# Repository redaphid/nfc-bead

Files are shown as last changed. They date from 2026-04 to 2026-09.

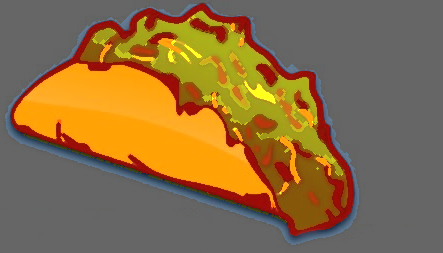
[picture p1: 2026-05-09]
beads/filibertos-taco/extract_debug.png

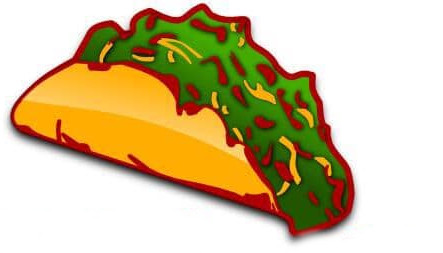
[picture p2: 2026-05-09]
beads/filibertos-taco/just-taco.jpg

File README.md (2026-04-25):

# nfc-bead

Reusable scaffolding for designing two-half snap-fit NFC charms / beads from a 2D silhouette SVG. Built around a Blender + Python pipeline that handles the boring mechanical bits (split, pegs, NFC pocket, string hole) so creative sessions can focus on the silhouette and aesthetic.

First charm built with this recipe: the [Wooli mammoth](https://github.com/redaphid/wooli-bead) (private). This repo is the template extracted from that work.

## What's in here

| Path | Purpose |
|---|---|
| `prompts/nfc-bead/prompt.md` | The technical recipe — dimensions, pipeline order, gotchas. Drop this into any new Claude session as the scaffolding for a new charm. |
| `.claude/skills/nfc-bead/SKILL.md` | Claude Code skill that auto-triggers on new-charm requests, loads the prompt, and drives the workflow. |
| `.claude/skills/nfc-bead/blender_mcp_addon.py` | Bundled Blender MCP addon (from [ahujasid/blender-mcp](https://github.com/ahujasid/blender-mcp)) so the live MCP workflow doesn't need an internet round-trip. |
| `.claude/settings.json` | Project Claude settings — pre-allows Blender / uvx / python invocations. |
| `.mcp.json` | Project-level MCP server config. Wires up the Blender MCP server (`uvx blender-mcp`). |
| `build_charm.py.example` | Reference implementation of the full Blender pipeline. Copy to `build_<charm>.py` and edit the CONFIG block at the top per charm. |
| `CLAUDE.md` | Working norms for Claude Code in this repo (branch model, multi-color defaults, live-MCP preference). |
| `SETUP.md` | One-time and per-session setup for the live Blender MCP workflow. **Read this if you want to drive Blender live**, otherwise headless works without it. |
| `tools/launch.ps1` | One-shot Windows launcher: opens Blender with the addon installed, enabled, and the MCP server running. See *MCP — Blender* below. |
| `tools/blender_bootstrap.py` | What `launch.ps1` actually feeds to Blender via `--python`. Idempotent. |
| `beads/<name>/` | Per-charm work tree: silhouette SVG, `build_<name>.py`, `print/` STLs + `.blend`, `stages/NN_*.blend` snapshots + `.md` notes, `DEBUGGING_LOG.md`. The rezz branch ships `beads/rezz/`. |
| `GUIDE.md` | Long-form walkthrough with lessons learned from the original Wooli build. |

## Quick start

1. **Branch off `main` for the new bead.** Per-charm work always lives on its own branch named after the bead — never on `main`:
   ```bash
   git checkout main && git pull --ff-only
   git checkout -b <bead-name>          # e.g. rezz, mammoth, octopus
   ```
2. Open this repo in Claude Code. The `nfc-bead` skill auto-loads.
3. Say something like: *"new charm — here's the silhouette"* and attach an SVG. The skill reads the prompt, asks the right questions, and walks the build. **Just talk to Claude — it knows about the branch convention, the launcher, and will run you through Blender setup if you don't have it going yet.**
4. Or, manually: read `prompts/nfc-bead/prompt.md` yourself, copy `build_charm.py.example` to `beads/<name>/build_<name>.py`, edit the CONFIG block, run headless:
   ```
   blender --background --python beads/<name>/build_<name>.py
   ```

## MCP — Blender (live workflow)

`.mcp.json` configures the [Blender MCP](https://github.com/ahujasid/blender-mcp) server (`uvx blender-mcp`) so Claude Code can drive Blender live — you watch geometry build in the viewport and can steer mid-build.

**One-shot launcher** — `tools/launch.ps1` opens Blender with the addon installed, enabled, and the MCP server running, all in one command:

```powershell
.\tools\launch.ps1                       # rezz bead (default)
.\tools\launch.ps1 -Bead wooli           # different bead's last-saved .blend
.\tools\launch.ps1 -BlendFile foo.blend  # arbitrary file
```

The launcher runs `tools/blender_bootstrap.py` inside Blender; it's idempotent (copies-if-stale + enables + saves prefs + starts server), so re-running it after a crash always brings you back to a working state. After Blender opens, run `/mcp` in Claude Code to (re)connect.

If you'd rather click through it manually, **[`SETUP.md`](./SETUP.md)** has the full step-by-step plus troubleshooting. Either way the bundled addon at `.claude/skills/nfc-bead/blender_mcp_addon.py` is what gets installed — no GitHub round-trip.

Headless `blender --background --python` works without any of this — the MCP is only for live interactive sessions.

## Default charm spec

| Feature | Value |
|---|---|
| Width | 25 mm (sized for Kandi bracelets) |
| Thickness | 5 mm (2.5 mm × 2 halves) |
| String hole | 2 mm dia, X-axis through head |
| NFC pocket | 10.5 mm dia × 0.8 mm deep (NTAG215, 10mm sticker) |
| Pegs | 3 × 2 mm dia × 1.5 mm tall, 0.1 mm clearance per side |

Override any of these per charm in the CONFIG block.

## Print settings

PLA or PETG, 0.12–0.16 mm layers, 100% infill, no supports. Bottom half flipped 180° around X (pegs face up, silhouette on build plate). Top half prints with peg-hole face on the build plate.

## License

Private template repo. Do whatever you want with it.

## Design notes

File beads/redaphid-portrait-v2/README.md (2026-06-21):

# Redaphid Portrait — v2 (new design)

The `redaphid-portrait` charm rebuilt on the "new design" learned from
`gymnast-medallion` (recipe gotchas #29–32), **keeping the portrait outline as
the bead shape** (NOT a round medallion). Same multi-color portrait — cream
face, magenta hair, glowing eyes — just slimmer with a one-sided string hole and
self-starting pegs.

## What changed vs the original `redaphid-portrait`

| Aspect | Original | v2 |
|---|---|---|
| Thickness | 4.0 mm symmetric (2.0 + 2.0) | **3.5 mm asymmetric**: Bottom 2.0 + Top 1.5 (slimmer decorated front) |
| String hole | 2.0 mm, on the split plane (half-groove each side) | **1.2 mm, entirely in the thick Bottom half** (gotcha #23/#31), ~0.4 mm walls |
| Pegs | 2.0 mm, 0.1 mm clearance, blunt | 2.0 mm, **0.05 mm clearance + 0.3 mm chamfered tips** (gotcha #29/#30) so they self-start instead of needing force |

Everything else is the original portrait pipeline: silhouette extrude → hole →
asymmetric split → NFC pocket → peg sockets (in Bottom) → pegs (on Top) → Hair
decoration (magenta) + Eyes (Decoration, glow). Pegs stay on Top per the
charm's chosen layout, so the Top prints **show-face-down** (hair/eyes on the
plate, pegs up); the build exports STLs already in that orientation.

## Source

- `silhouette.svg` + `hair.svg` copied from `beads/redaphid-portrait` (tuned).
- `extract_silhouette.py` (reference) re-extracts both from the source
  screenshot `C:\Users\hypnodroid\Pictures\Screenshots\Screenshot 2026-04-25 235837.png`.

## Files

| File | What |
|---|---|
| `silhouette.svg` / `hair.svg` | portrait outline (+eyes) and haircut shape |
| `build_redaphid.py` | headless Blender build → 4 STLs + blend (+ direct print-oriented export) |
| `print/Bottom.stl` | cream — thick back half: NFC pocket, peg sockets, string hole |
| `print/Top.stl` | cream — thin front half + pegs (prints show-face-down) |
| `print/Hair.stl` | magenta — raised haircut |
| `print/Decoration.stl` | glow — the two eyes |
| `print/redaphid-portrait-v2.3mf` | slicer bundle (Bottom + Top+Hair+Decoration merged) |
| `preview.png` | render (viewed from the show-face side) |

## Rebuild

```sh
"D:\tools\blender\blender.exe" --background --python beads/redaphid-portrait-v2/build_redaphid.py
uv run nfc-make-3mf --dir beads/redaphid-portrait-v2/print --out beads/redaphid-portrait-v2/print/redaphid-portrait-v2.3mf
```

## Verified

All four parts watertight (Decoration = 2 eyes = 2 bodies, expected). String
hole open in the Bottom (ray cast: solid/void/void/solid, 0.4 mm walls). Pegs
single-body welded to Top with chamfered tips. Three peg positions pass the
silhouette + NFC + hole clearance checks.

## Watch on print

- 0.4 mm walls around the 1.2 mm string hole bridge fine on a tuned printer; bump `BOTTOM_THICK` toward 2.2 mm if they sag.
- Top prints show-face-down — the multi-color hair/eyes are the first layers (mind the bed finish). The original tracked this as `top-v5b-1stlayer`.

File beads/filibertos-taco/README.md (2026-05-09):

# Filiberto's Taco

A two-half NFC charm shaped like a cartoon taco — yellow shell, green lettuce, red outline — built as a multi-color print on the Centauri Carbon 2.

## Source

- `just-taco.jpg` — the reference cartoon taco art (yellow shell + green lettuce + red outline on white background).
- `silhouette.svg` — outer body silhouette extracted from the JPEG via custom multi-color extraction (Pillow + numpy + scipy + skimage). Single Fourier-smoothed closed path, 400 verts.
- `region_yellow.svg`, `region_green.svg`, `region_red.svg` — color-segmented decoration regions in the same coordinate frame as `silhouette.svg`.
- `extract_debug.png` — segmentation overlay (blue=outer, red=outline, yellow=shell, green=lettuce). Sanity-check before importing.

The original `taco.svg` Potrace tracing was discarded — it was a B&W line-art trace, not a filled silhouette, and produced a hollow body with even-odd fill. The JPEG-based extraction yields a clean filled outer outline plus three color regions.

## Why this charm exists

Exercises the multi-color decoration pattern: rather than a single `Decoration` object, the show face hosts three overlapping color regions (yellow shell base, green lettuce on top, red outline detail) extruded as raised relief. Slicer assigns one filament per region.

It also stress-tests the SVG → silhouette pipeline against a *bitmap* input — Potrace traces of pen-and-ink illustrations don't make clean filled silhouettes; you need a color-aware mask of the colored regions. That extraction lives at the top of `build_filibertos_taco.py` documentation, not as a generalized skill (yet).

## Key creative decisions

| Decision | Cost |
|---|---|
| Multi-color decoration as 3 separate STLs (Yellow / Green / Red) | More slicer setup; user assigns filaments per object. Simpler than paint-on-color in Bambu Studio / Elegoo Slicer. |
| Show face raised relief (0.4 mm) instead of recessed groove | Bumpy show face but reliable bridge-free print; recess would need the slicer to color-paint the same Top STL. |
| String hole tube entirely inside Top half (`HOLE_Z_OFFSET=1.25`) | First-layer adhesion is solid silhouette across the seam; tube becomes a small interior cavity bridged twice (~0.5 mm wall above and below). Recipe gotcha #23. |
| Bottom in print orientation already at end of build (centered-mesh pipeline) | Sets `nfc_export_flip_override` so `bead-stl-export` doesn't apply its default 180° flip. Recipe gotcha #16. |
| 3 pegs (not 4) at `(7.5,-6.0)`, `(-9.5,0.0)`, `(7.5,2.5)` | Triangulated; auto-fit found ≥1mm clearance from NFC and silhouette boundary, ≥1mm from string-hole tube. |
| Concatenate the 3 color STLs into a unified `Decoration.stl` for the 3MF builder | Lets `nfc-make-3mf` ship a slicer-ready bundle. Per-color STLs remain separate in `print/` for users with multi-filament setups who want explicit per-region color control. |

## What's transferable / what's specific

**Transferable** (could become recipe defaults):
- `nfc_export_flip_override` discipline for centered-mesh build pipelines — already in recipe gotcha #16.
- Multi-color decoration as raised relief at `top_z + ε` rather than recessed cuts.
- Cropping decorations to silhouette via boolean INTERSECT with a duplicate-extruded Top.

**Specific** (tuned to this taco):
- Custom extraction script at the top of `build_filibertos_taco.py`'s sibling files. It assumes a white-background cartoon with red/yellow/green color clusters. Other illustrations will need per-charm tuning of the channel-discriminator thresholds.
- 25 mm × 17 mm bounding box with NFC at `(0, 0.5)` and `HOLE_Y=5.0` — auto-fit picked these for this silhouette's specific shape.

## Files

| File | What it is |
|---|---|
| `just-taco.jpg` | source reference image |
| `silhouette.svg` | outer body silhouette (used by `build_filibertos_taco.py`) |
| `region_yellow.svg` / `region_green.svg` / `region_red.svg` | color region inputs |
| `extract_debug.png` | extraction sanity overlay |
| `build_filibertos_taco.py` | Blender pipeline — extrude → split → NFC + hole + pegs → 3 decoration extrudes |
| `print/Bottom.stl` | back half — silhouette face on bed, pegs up |
| `print/Top.stl` | front half — peg sockets in inner face, show face up |
| `print/DecorationYellow.stl` / `DecorationGreen.stl` / `DecorationRed.stl` | per-color decoration regions, 0.4 mm raised relief on Top |
| `print/Decoration.stl` | concatenation of the 3 color STLs (used by `nfc-make-3mf`) |
| `print/filibertos-taco.3mf` | Bambu Studio / Elegoo Slicer bundle (Bottom + Top with Decoration assembly) |
| `print/filibertos-taco_charm.blend` | live Blender scene at end of build — re-launch via `tools/launch.ps1 -Bead filibertos-taco` |
| `stages/01_built_verified.blend` | snapshot at the post-build verification step |
| `PRINT_LOG.md` | per-print iteration log (failure modes + parameter changes) |

## Two style variants

Build script `build_filibertos_taco.py` switches between two looks by
reading `STYLE` (env var `FILIBERTOS_TACO_STYLE`, scene custom prop
`nfc_taco_style`, default `"painted"`):

| Style | Decoration source | Output |
|---|---|---|
| `painted` (default) | `region_*.svg` (filled color regions, k-means extraction) | `print/` — 4-filament cartoon look |
| `neon` | `stroke_*.svg` (line strokes, dilate-XOR extraction) | `print/neon/` — 2-3-filament neon-sign look on a black body |

Switch in Blender:
```python
bpy.context.scene["nfc_taco_style"] = "neon"
exec(open(r"...build_filibertos_taco.py").read(), {"__name__":"__main__"})
```

Re-extract decoration sources independently:
```sh
uv run python beads/filibertos-taco/extract_regions.py   # k-means → region_*.svg
uv run python beads/filibertos-taco/extract_strokes.py   # dilate-XOR → stroke_*.svg
```

## Re-build / re-export

```sh
# from a fresh shell, in the repo root:
.\tools\launch.ps1 -Bead filibertos-taco
# in Claude Code:
/mcp                       # reconnect bridge
# Then in conversation:
exec(open(r"D:\Projects\nfc-bead\beads\filibertos-taco\build_filibertos_taco.py").read(), {"__name__": "__main__"})
```

The build sets `nfc_export_flip_override` automatically. After it completes:

```sh
# back in the host shell:
uv run python -c "import trimesh; from pathlib import Path; LAT=Path('tmp/latest'); parts=[trimesh.load(LAT/n) for n in ('DecorationYellow.stl','DecorationGreen.stl','DecorationRed.stl')]; trimesh.util.concatenate(parts).export(LAT/'Decoration.stl')"
uv run nfc-printability-check
uv run nfc-make-3mf
```

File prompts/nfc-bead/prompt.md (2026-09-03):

# NFC Bead / Charm — Technical Recipe

Use this as the technical scaffolding for any new two-half NFC charm. Drop it in at the start of a session, then describe the *creative* side — silhouette, theme, vibe, dimensions if non-default — and let the rest follow this recipe.

A working reference implementation lives at `build_charm.py` in this repo (built for the Wooli mammoth). Treat it as the canonical pipeline; copy and adapt the CONFIG block for new charms.

---

## What we're building

A **two-half snap-fit charm** for Kandi-style bracelets:

- A 2D silhouette (from SVG) extruded to a flat-ish 3D shape
- **Cut horizontally through the middle** into a top half and a bottom half
- **NFC sticker pocket** recessed into the inside face of the bottom half (so the sticker sits flush)
- **Friction-fit pegs** on the bottom half + matching holes on the top half (no glue — press fit)
- **String hole** through the head/top so it can hang off a bracelet or cord

Target NFC tag: NTAG215, 10mm diameter sticker (e.g. `https://www.amazon.com/dp/B0CH3XS569`). Pocket sizing assumes that.

---

## Default dimensions (override per-charm as needed)

| Feature | Value | Notes |
|---|---|---|
| Overall width | 25 mm | sized for Kandi bracelets; scale on import |
| Total thickness | 5 mm | split as 2.5 mm + 2.5 mm |
| String hole | 2 mm dia | runs along the X axis (lengthwise through the head/top) |
| NFC pocket | 10.5 mm dia × 0.8 mm deep | on the inside face of the bottom half only |
| Peg diameter | 2 mm | bumped up from 1.5 — stronger, less prone to snapping |
| Peg height | 1.5 mm | |
| Peg hole clearance | 0.1 mm per side | so hole radius = (peg_dia + 0.2) / 2 |
| Number of pegs | 3 | triangulated for stable alignment |

**Peg placement rules** (pick 3 spots that satisfy all of these):
- Inside the silhouette (raycast-verify before committing)
- ≥ ~1 mm clear of the NFC pocket edge
- ≥ ~1 mm clear of the string hole
- Triangulated, not collinear (gives torsional stability)
- ≥ ~1 mm from the silhouette edge (so the wall around the peg hole isn't paper-thin)

**String-hole placement rules** — the hole hangs the bead off a bracelet, so the
wall around it is a load-bearing feature. Don't pick the obvious spot if it
leaves thin material:

- Y must sit on a *wide* part of the silhouette — not on a narrow tip, ear-
  flap, hair-ridge, or other protrusion. Aim for the band where the
  silhouette is at full width.
- ≥ 2.5 mm of solid silhouette **above** the hole (between hole top and the
  silhouette's top edge). With a 2 mm-dia hole that's ≥ 1.5 mm of wall above.
  Less than that, the bead snaps off the bracelet under load.
- ≥ 1.5 mm of solid silhouette to either side at the hole's Y. The hole runs
  along X, so the silhouette's X-extent at the chosen Y must comfortably
  exceed the bead's diameter at the hole.
- For shapes whose top is a narrow protrusion (mammoth tusk, shaggy hair
  bumps, animal ears), drop the hole *down* into the wider head/forehead
  body even if it costs aesthetic intent. The dangling bead doesn't notice
  where the cord exits, but the wall above does.

---

## Pipeline (in order — order matters)

```
SVG silhouette
  → Import into Blender as 2D curve, join, set fill_mode='BOTH', resolution_u=64
  → Convert to mesh, scale to TARGET_WIDTH (mm)
  → Fill any interior gaps that would conflict with features (NFC pocket, pegs)
  → Extrude flat profile to THICKNESS  (use Extrude, NOT Solidify)
  → Boolean DIFFERENCE for the string hole (full bead, before split)
  → Box-cut INTERSECT to split into top + bottom halves at z_mid
  → Boolean DIFFERENCE for NFC pocket on the bottom half
  → Boolean DIFFERENCE for peg holes on the top half  (POST-SPLIT — see gotcha)
  → Boolean UNION to add pegs onto the bottom half     (NOT mesh join)
  → Flip bottom 180° around X for printing; export both STLs
```

---

## Critical gotchas (these will bite you if ignored)

### 1. Cut peg holes AFTER splitting, never before
If you cut peg holes into the full bead first and then box-cut to split, the split plane is **coplanar** with the peg-hole bottom. The EXACT solver collapses the holes — they get sealed shut and disappear silently. Always split first, then cut peg holes into the top half with cutters that extend **1 mm below the inner face** so the cutter is unambiguously through-going:

```python
cutter_bottom = inner_face_z - 1.0          # extend past the inner face
cutter_top    = inner_face_z + PEG_HEIGHT + 0.3
```

### 2. Always use the EXACT boolean solver
`solver = 'EXACT'`. The FAST solver routinely produces non-manifold output on shapes like this. Set this on every modifier.

### 3. Add pegs with boolean UNION, not mesh join
`bpy.ops.object.join()` leaves overlapping coplanar faces where the peg cylinder meets the inner face → 1000+ non-manifold edges. Use a UNION boolean modifier instead. It welds the peg to the half cleanly.

### 4. Use Extrude, not Solidify, when the silhouette has interior holes
Solidify produces broken topology around interior boundaries (e.g., the gap between mammoth legs, the inside of an "O"). Plain extrude is clean.

### 5. Tight `remove_doubles` threshold
Use `0.005` mm. `0.02+` will collapse small features and ruin the geometry. Run `remove_doubles` + `normals_make_consistent(inside=False)` after every boolean.

### 6. Filling interior gaps cleanly
If the silhouette has an interior hole that overlaps a feature (e.g., an NFC pocket lands on the trunk-gap hole), don't try to patch it in the SVG with an overlapping rectangle — that creates a separate boundary that won't merge. Instead, in mesh edit mode, select the boundary edges of the unwanted hole by coordinate range and call `bpy.ops.mesh.fill()`. Other interior holes you want to keep (like the leg gap) are untouched.

### 7. Don't voxel-remesh
Voxel remesh seals small holes (string hole, peg holes) at any reasonable resolution. Skip it.

### 8. Verify everything with raycasts before exporting
After the build, raycast through where each hole should be:
```python
result = eval_obj.ray_cast(origin, direction)
# result[0] is True if it hit something — i.e. the hole is BLOCKED
```
Verify: string hole open through the head, each peg hole open through the top, each peg position lands on solid geometry inside the silhouette.

Note: peg holes are *blind* recesses (cutter depth = `PEG_HEIGHT + 0.3 mm`), not through-going. The raycast through a peg hole will *intentionally* report `BLOCKED at z=PEG_HEIGHT+0.3`. That's the right answer — they're sockets the pegs bottom into.

### 9. Build raised face decorations as flat ribbon meshes, not curve-bevel-then-clip
For any raised graphic on the show face (rezz spiral, embossed text, ridged pattern), the obvious workflow — build a curve, set `bevel_depth = arm_width / 2` for a tube cross-section, convert to mesh, then INTERSECT with a slab to flatten — **silently produces an empty mesh**. The EXACT solver doesn't reliably handle a tube tangent to a thin slab; it collapses the entire mesh. No error is raised; you'll see `dims: (0.0, 0.0, 0.0)` in the output and a missing object in the viewport.

Build the ribbon directly instead. Sample the centerline path, compute inner/outer offsets perpendicular to the tangent, build quads with `mesh.from_pydata`, extrude vertically. Reliable, manifold, fast.

Do **not** add an explicit "end-cap" face to close the open ends of an open ribbon. A face like `[inner_start, outer_start, outer_end, inner_end]` will draw one gigantic quad spanning from start of the ribbon to end, visible as a straight line cutting across the disc. Extrusion auto-creates side-wall faces along the boundary edges, which closes the ends as small rectangular walls — no explicit cap needed.

### 10. Don't `origin_set BOUNDS` on objects whose mesh-local origin is meaningful
If an object's mesh was built around a meaningful origin point (the centerline of a spiral, the centroid of a silhouette), running `bpy.ops.object.origin_set(type='ORIGIN_GEOMETRY', center='BOUNDS')` before placing it will move the *bbox center* to that origin — but for an asymmetric mesh (e.g. a spiral with a notch trimmed out, an outline with a tail), the bbox center isn't where the meaningful origin was. The object lands subtly off-center.

`origin_set BOUNDS` is for objects whose origin doesn't matter (`Bottom`, `Top` halves — they were extruded from a centered silhouette and bbox center matches geometric center). Skip it for decorations whose mesh-local `(0,0,0)` is geometrically significant; place them via `obj.location` directly.

### 11. Lift overlapping decorations by ε to avoid Z-fighting
When a separately-printed decoration (raised spiral, embossed text) sits on the host face, both at the same Z, viewport rendering will Z-fight at the boundary. Lift the decoration by 0.01 mm (`spiral.location.z = host_top_z + 0.01`). Slicer tolerances absorb this — they print fused — and the viewport is artifact-free.

### 12. Don't cut decorative "clearance" against features the decoration never touches
A common reflex is to trim the show-face decoration around features like the string hole "for clearance." If the feature physically interacts with the decoration, yes — trim. But the string hole runs *horizontally through the bead body*; the decoration sits on the *outer face*; they never touch. Cutting a notch in the decoration to "clear" the hole's top opening just leaves a visible bite in the decoration that adds nothing functional. Question whether the cut is necessary before adding it.

### 13. Drill the string hole at the mesh's *actual* z-midpoint, never at `THICKNESS/2`
If your build pipeline centers the FullBead on the origin (so verts span `−THICKNESS/2..+THICKNESS/2`), hard-coding `location=(0, HOLE_Y, THICKNESS/2)` puts the hole at the **top face** of the bead — entirely inside the Top half after the box-cut split. Bottom ends up with no opening, and you can't thread a cord through. Compute `z_mid` from the live mesh:

```python
zs = [v.co.z for v in mesh.data.vertices]
z_mid = (min(zs) + max(zs)) / 2.0
location = (0, HOLE_Y, z_mid)
```

This is silent — the build runs to completion, the STL passes manifold checks, and you only notice when you try to thread a cord (or run a side-view raycast). The reference `build_charm.py.example` doesn't trip this because it leaves the silhouette at z=0..THICKNESS rather than centering it; centered-mesh builds need the live z_mid.

### 14. Pegs go on Bottom — multi-color decoration on Top precludes flipping it
The recipe's "pegs on Bottom + sockets on Top" assignment isn't arbitrary. With pegs on Top hanging *down* off the inner face, the slicer flags the Top assembly as a cantilever (the body is suspended on three thin pillars). The natural fix — flipping Top so pegs point *up* — doesn't work either, because the show-face decoration (Hair slab, raised eyes) would then point INTO the build plate. Pegs *must* live on Bottom for any charm with raised decoration on Top.

### 15. Importing a subset SVG into the silhouette's frame requires a viewBox-shift
When the build script imports a second SVG that's a *subset* of the silhouette (e.g. a `hair.svg` that traces only the haircut region of the same viewBox), Blender's `bpy.ops.object.origin_set(type='ORIGIN_GEOMETRY', center='BOUNDS')` re-centers the imported curve on its own bbox, NOT on the viewBox. Two SVGs with the same viewBox end up overlapping their bbox centers at world (0,0) — which mis-aligns them, since the silhouette's bbox-center IS the viewBox-center but the subset's isn't.

Fix: parse the subset's path bounds and the viewBox dimensions out of the SVG, and shift the imported subset by `(subset_cx − viewBox_cx, viewBox_cy − subset_cy)` mm (Y-flip because Blender Y is up while SVG Y is down). Set `obj.location = (shift_x, shift_y, 0)` — don't *add* to the location after `origin_set`, since `origin_set` already moved the location to the world position of the bbox-center.

### 16. The build pipeline's print orientation may not match the export skill's flip dict
`bead-stl-export/export.py` defaults to flipping Bottom 180° around X — that assumes the live scene has Bottom *upside-down* (silhouette face UP, pegs DOWN), so the flip lands silhouette-on-plate-pegs-up for printing. A *centered-mesh* build pipeline (FullBead centered on origin) produces Bottom *already* in print orientation (silhouette DOWN, pegs UP); applying the flip un-orients it.

Override per build by setting `bpy.context.scene["nfc_export_flip_override"]` to a JSON dict before running the export skill:

```python
import json
bpy.context.scene["nfc_export_flip_override"] = json.dumps({
    "Bottom": 0.0, "Top": 0.0, "Hair": 0.0, "Decoration": 0.0,
})
```

Other beads using the canonical flipped-build pattern keep the default behavior.

### 17. `bpy.ops.read_factory_settings()` unloads the BlenderMCP addon
"Wiping the scene to a clean slate" via `bpy.ops.wm.read_factory_settings(use_empty=True)` also unregisters the BlenderMCP addon — silently dropping the MCP socket. Subsequent `mcp__blender__*` calls fail with "Could not connect to Blender." Either delete objects/collections explicitly instead of factory-resetting, or relaunch Blender via `tools/launch.ps1` (which re-installs the addon and restarts the socket).

### 18. `exec(open(script).read())` doesn't trigger `if __name__ == "__main__"`
When you run a build script through Blender MCP via `exec(open(...).read())`, the script's `__name__` is the *calling* module, not `"__main__"` — so any `if __name__ == "__main__": main()` at the bottom never fires. Pass an explicit namespace:

```python
ns = {"__name__": "__main__"}
exec(script, ns)
```

This is the same trap as running scripts via Blender's `--python` flag in some contexts; either pass the namespace or call `main()` directly.

### 19. `gaussian_filter` blurs the channel axis too — use per-axis sigma for color images
`scipy.ndimage.gaussian_filter(rgb, sigma=4.0)` smears RGB channels into each other along with spatial pixels — saturation collapses to ≈ 0 because the R/G/B values converge. For color-aware extraction (face vs outline by hue), use:

```python
ndimage.gaussian_filter(rgb.astype(np.float32), sigma=(BLUR, BLUR, 0))
```

The `(s, s, 0)` tuple blurs height/width but leaves channels untouched.

### 20. Stale `FullBead` (or other helper) duplicates accumulate across rebuilds
Re-running a build script that creates intermediate objects (`FullBead`, peg cylinders, cutters) without first wiping them produces `FullBead.001`, `.002`, etc., that pile up in the scene. They're hidden, but they cost memory, slow boolean operations, and confuse later raycasts that walk `bpy.data.objects`. Either clear them explicitly at the top of the build:

```python
for n in list(bpy.data.objects.keys()):
    if n.startswith("FullBead"):
        bpy.data.objects.remove(bpy.data.objects[n], do_unlink=True)
```

or wipe the whole scene at the start of the build (but mind gotcha #17 — don't `read_factory_settings`).

### 21. `verify_pegs` must raycast the peg PERIMETER, not just the center
A center-only raycast confirms the silhouette is solid at the peg's XY but does NOT confirm that the peg's full cylindrical footprint is inside the silhouette boundary — a peg whose center is 0.3 mm inside silhouette y-min still has 0.7 mm of its 1 mm-radius edge poking past the boundary, producing visible bumps on the silhouette outline AND a thin material backing where the peg meets the bead body. The recipe shipped with this bug for several charm revisions before it was caught visually on a printed bead.

The fix (implemented in `build_charm.py.example`): raycast the center plus 8 evenly-spaced perimeter points (`k * π / 4` for k in 0..7) at the peg radius. Any miss → reject the peg position. The build now refuses to proceed if any configured peg has perimeter clipping; tighten `PEG_CANDIDATES` until every peg passes.

Two layered guards:
- **Build-time**: the perimeter raycast above; rejects bad peg positions before any boolean is applied.
- **Post-export**: `bead-printability-check` skill's "peg edges inside silhouette" check re-validates against the final STL.

A peg edge protruding by ≤ 0.5 mm is usually cosmetic; protrusion by ≥ 1 mm means the peg has thin material around it and may break under press-fit pressure.

**Corollary**: don't assume `silhouette_y_min == -THICKNESS/2 == -h/2`. A portrait silhouette can be height 16.92 mm but extend asymmetrically (e.g. y ∈ [-8.44, +8.46]) once it's centered by the pipeline. *Measure* the silhouette extent against the live mesh when picking peg positions, don't compute from the silhouette dimensions alone.

### 22. Re-export after every Blender edit before slicing
The exported STLs and 3MF live separate from the .blend. When you make a tweak in Blender (move a peg, retune hair, fix a non-manifold) and save the .blend, the print bundle is **stale until you re-run `bead-stl-export`**. Importing the old 3MF into the slicer "to check the change" silently loads the un-tweaked bead — you debug the wrong artifact for half an hour before realizing.

The forward-only protocol: every Blender edit ends with `exec(...)` of the export skill. Build → export → make-3mf is a chain; running only one link leaves a stale tail.

### 23. Splitting the string hole across the seam costs first-layer adhesion
The recipe-default places the string hole on the Z midplane, so each half hosts an open half-circular groove on its inner face. When the half is printed inner-face-down (Top is printed face-up → inner face on bed; Bottom flipped silhouette-down → inner face is the *top* of the print), that 1.5–2 mm gap in the silhouette outline at `y=HOLE_Y` is right where the bed meets the part. Bed-contact area drops; mid-print the part can lift slightly at the hair band; multi-color swap purges that land near that region peel and the head drags them.

The fix is structural: set `HOLE_Z_OFFSET` to ~`THICKNESS/4` so the entire hole sits inside one half, with the inner face fully solid silhouette at `y=HOLE_Y`. The hole becomes a small interior tube that the slicer bridges twice (floor + ceiling, ~1.5 mm spans, easy bridges). Cost: tube wall thickness above + below shrinks to `(half_thickness - hole_dia) / 2` ≈ 0.5 mm at THICKNESS=5 — printable on a tuned printer, marginal on others. If the print still fails, bump `THICKNESS` rather than reverting to the split-plane hole.

### 24. NFC pocket needs the same perimeter raycast as pegs
Mirrors gotcha #21 but for the NFC pocket. Center-only validation passes if the pocket center is inside the silhouette, but a 5.25 mm-radius pocket centered 4 mm from the silhouette boundary clips past it on one side — leaving a paper-thin or open wall along that arc. The first time this happened the user had to look at the slicer's 3D view to spot it; the build script declared success.

The fix (implemented in `build_charm.py.example`): 16-point raycast (`k * π / 8` for k in 0..15) at the NFC radius. Any miss → reject the position; print the per-vertex misses so the user can pick a better `NFC_POS` or shrink `NFC_DIAMETER`. More samples than the peg check (16 vs 8) because the NFC radius is much larger and a single missed sample represents a wider arc.

### 25. Multi-region SVG round-trip silently breaks alignment between regions
For a multi-color charm with N region SVGs (filling, shell, outline, interior detail), Blender's `import_curve.svg` sizes each imported curve from the **path bbox**, not the SVG `viewBox`. Auto-fit-to-target-width then scales each region by its own path extent — so a region whose path covers 95% of the viewBox lands at scale ≈ 1.05× what a region covering 40% of the viewBox lands at. The two regions end up at different scales AND different positions even though their viewBoxes are identical.

You won't notice on the body silhouette (its path always covers the full viewBox). You will notice when an interior-detail SVG with fragments clustered in one corner gets auto-fit to 25 mm wide and stretches the fragments to fill that width — they end up at the wrong positions and the wrong size relative to silhouette + filling.

Two fixes, in order of cleanliness:
1. **Polygon manifest pipeline** (preferred for multi-region charms): emit each region's polygon vertices in shared mm coordinates to a single `regions.json`, then build Blender meshes via `bmesh.from_pydata`. No SVG round-trip. See `beads/filibertos-taco/extract_regions.py` for the reference.
2. **Bbox-anchor markers in SVG** (lighter touch): in your SVG writer, always emit two 1-pixel `<rect>` markers at the silhouette's bbox corners. Forces every SVG's path bbox to match the silhouette's, so per-SVG auto-fit gives consistent scale.

### 26. Decoration cropper must be a fresh silhouette extrusion, never a duplicate of Top
When you crop a decoration (e.g. multi-color slab) to the silhouette outer boundary via boolean INTERSECT, the natural reflex is to duplicate Top, raise its show-face vertices, and use that as the cropper. **This punches the peg-socket holes through the decoration**: Top has the peg sockets cut into its inner face, those holes become open through-tubes when the show face is raised, and the INTERSECT cuts matching holes in the decoration above each peg position. You see 3 visible bare-show-face circles on the decoration in the slicer.

Fix: build the cropper from a fresh re-import of `silhouette.svg` extruded tall — no peg sockets, no NFC pocket, no string hole. `build_charm.py.example` provides `_build_silhouette_cropper()` for exactly this. **Do this for every multi-color charm** — the bug is invisible until you slice.

### 27. Multi-color decoration layers need ≥0.16 mm Z-step or the slicer will Z-fight
When you stack multiple raised decoration objects on the show face — base color slab, accent color, outline ring — they need clear Z separation. A z-step less than the slicer's typical layer height (0.16 mm) leaves the slicer ambiguous about which filament wins on a given layer; the imported model looks like one decoration is missing or showing through the wrong one.

Recipe-default `DECO_LAYER_STEP = 0.10 mm` is below typical layer height for tightness BUT only safe when no two decorations overlap in XY. If they DO overlap (filling under a separator curve, separator under outline ring), bump to `0.20 mm` so each is unambiguously its own slice. The decoration relief is 0.4 mm tall, so 0.2 mm × 4 layers = 0.8 mm total height stack — still well within the bead's 5 mm thickness.

Stack order in the build's `BLOCK_GROUPS` dict matters: things at higher layer_idx get higher Z and OCCLUDE things below them in the slicer's view. Put the visually-dominant decoration last so it's never occluded.

### 28. Multi-decoration 3MF: bundle as a `ComponentsObject` with one build item
The 3MF you ship to the slicer for a multi-color charm should have ONE `<components>` object with all Top-frame meshes (Top + every Decoration*) referenced as components, and ONE `<build>` `<item>` placing that assembly on the plate. Adding each mesh as its own top-level `<object>` with its own `<item>` (5+ build items at the same XY) confuses every slicer we've tried — Bambu Studio reports "model is too small" and offers to scale 25×, Elegoo Slicer flips one half upside-down. The ComponentsObject keeps everything anchored together.

Trade-off: the slicer renames component children with a numeric suffix (`top_with_decorations_1` etc.). That's cosmetic — the user can rename in the slicer. The "fix" of removing the ComponentsObject for cleaner names breaks the 3MF.

`tools/make_3mf.py` already follows this pattern for the canonical Bottom + Top + Decoration + Hair set. For charms with more decoration layers, write a per-charm `bundle_3mf.py` (mirror of `make_3mf.py`'s structure but with the charm's full decoration list) — see `beads/filibertos-taco/bundle_3mf.py` for the reference.

### 29. Snap-fit peg tuning: 2.6 mm dia, 0.05 mm radial clearance
The recipe-default **2.0 mm pegs at 0.1 mm clearance don't grip** — they're too narrow and too loose; the halves fall apart ("pegs don't fit together"). redaphid-portrait v5/v6 nailed the actual snap-fit on the Centauri Carbon 2 at **2.6 mm dia + 0.05 mm radial clearance** (so `hole_r = (PEG_DIAMETER + 0.1) / 2`). `build_charm.py.example` ships these defaults. At a small bead (≤20 mm) check `peg_radius` clearance to the NFC pocket edge — 2.6 mm pegs need the peg ring at radius ≥ ~7.5 mm around a centered 10.5 mm pocket.

### 30. Chamfer the peg TIPS or they catch on the socket rim
Even at the correct clearance, **blunt (flat-top) pegs catch on the socket opening and have to be forced together** — the user literally had to bite down on a printed bead to seat them. The grip is fine; the *entry* is the problem. Add a lead-in taper to the tip: keep a full-diameter shaft of `PEG_HEIGHT − PEG_CHAMFER`, then a cone frustum from full radius down to `radius − PEG_CHAMFER` over `PEG_CHAMFER` (~0.35 mm). The narrow tip self-centers into the socket, then the chamfer guides the full shaft in. Do NOT loosen the clearance to fix entry — that costs grip. `build_charm.py.example` Step 10 builds this (shaft cylinder + cone tip, both UNIONed). **Gotcha within the gotcha:** the cone tip must OVERLAP the shaft (~0.15 mm), not butt against it coplanar — a coplanar UNION doesn't merge and the tip exports as a SEPARATE body (non-watertight, prints as a loose cone). Shift the cone back into the shaft by the overlap.

### 31. Slimming a bead: thin ONE half asymmetrically, and move the string hole to the thick half
To make a bead thinner than the default 2×2.5 mm, don't thin both halves equally — the deep features set a per-half floor. The **socket-host half must stay thick** (peg sockets are `PEG_HEIGHT + 0.3` deep, and pegs *must* live on Bottom so sockets are in Top — gotcha #14), so thin the OTHER half. The thin half can only host the shallow NFC pocket (0.8 mm) + peg bases (pegs rise *above* the inner face, so they don't consume that half's thickness). Two consequences:
- The **string hole must live in the thick half** (single-half hole, gotcha #23) — a 1.5 mm half can't host even a 1.2 mm hole with printable walls.
- Split at an **asymmetric seam** (`z_split = z_min + BOTTOM_THICK`), not the geometric mid-plane.

Reference: `beads/gymnast-medallion` runs Bottom 1.5 mm + Top 2.0 mm + 0.5 mm relief = 4.0 mm total (down from 5.5), with the hole in the 2.0 mm Top.

### 32. Round "medallion" beads: procedural cylinder base + a figure silhouette as the raised relief
For a round bead with a figure (not a spiral) raised on the show face — like `beads/gymnast-medallion`:
- **Build the round base as a `primitive_cylinder` (≥128 verts), not an SVG.** A circle doesn't need a traced outline, and the cylinder is exact + clean. Centre it on z=0 and run the same hole→split→NFC→pegs pipeline.
- **The decoration is a plain extruded silhouette polygon** (figure → ngon → extrude `RELIEF_HEIGHT`), placed on the Top show face + ε. The rezz "flat ribbon" workaround (gotcha #9) is only for tube-section curves; a *filled* figure extrudes cleanly. Thin limbs are fine on a relief — they sit on the solid show face.
- **Mass-center the relief on its area centroid, NOT its bbox center.** A figure with a long thin limb (an extended leg, a pointed toe) has a bbox center far from its visual mass; centering on the bbox leaves it looking shoved to one side. Use the shoelace area-centroid, then **scale by max radial extent** (`FIT_RADIUS / max_dist_from_centroid`) so the whole figure — including the sprawling limb — sits inside the circle with no clipped edges. Centering on the bbox or scaling by "longest side" both clip or off-center it.

### 33. A 3MF without a printer profile silently loses the brim

The `shield` bead failed to print and the geometry was never the problem. Its 3MF was three files — geometry only, **no `Metadata/project_settings.config`** — so Elegoo Slicer fell back to whatever preset happened to be loaded, which had no brim. The medallion that printed clean carried a 34 KB `project_settings` with `auto_brim`/5 mm.

**The brim wins.** `print/PRINT_GUIDE.md` says no brim; the first-layer adhesion diagnosis says use one. Resolve it in favour of the brim: a bead is a small flat slab with little plate contact, and it lifts without one.

Related: the package must also *look* like the slicer's own output. Elegoo Slicer warns "the 3mf file you are importing may be incompatible" when the `Application` metadata names a tool it doesn't recognise, and a package it treats as foreign may **also ignore the embedded `project_settings`** — dropping the brim and reproducing the exact failure the template exists to prevent. `tools/build_3mf.py` adopts the template's own producer string and plate thumbnails for this reason.

### 34. Filament slot 2 is RED — a single-colour bead must say slot 1

`build_3mf.py` historically hardcoded every part to extruder 2, a leftover from the multi-colour redaphid recipe where the body was red and the decoration black. **A single-colour bead built to print black printed RED, silently.** Nothing caught it, because every check in the pipeline is a geometry check and this is not a geometry problem.

Pass `--body-extruder 1` for single-colour beads, and verify by reading the artifact back rather than trusting the log:

```
python -c "import zipfile,re; z=zipfile.ZipFile(P); print(re.findall(r'key=.extruder. value=.(\d+).', z.read('Metadata/model_settings.config').decode()))"
```

All `1` for a black/glow bead. Any `2` is this bug.

### 35. A `.3mf` is a project file, not a print job

The printer only runs sliced `.gcode`. A generated 3MF uploads happily and then sits inert — it lists with `layer: 0`, `print_time: 0`, `color_map: []`, against populated values on every file that has really printed. **Check those fields before starting a print.**

There is no slicer installed on the build machine, so **3MF → gcode cannot be done headlessly**. An agent can rebuild geometry and bundles unattended but cannot get a *new* design onto the plate; that step needs a human in Elegoo Slicer once. Only an already-sliced gcode can be started remotely.

### 36. Back the part cooling off for the first layers, or the edges curl

The stock profile ships `close_fan_the_first_x_layers=1` and `full_fan_speed_layer=0`, so cooling hits 100% from layer 2 — observed live at 232–250 of 255. On a small flat PLA slab that is a textbook edge-curl driver: the upper layers contract hard while the first layer is still pinned to the plate. These beads have no real overhangs, so the aggressive early cooling buys nothing; `overhang_fan_speed` still covers the string-hole bridge. `build_3mf.py` now holds the fan off 3 layers and ramps to full by 5.

**Also worth knowing before diagnosing a "hung" print:** there are ~12 minutes of preamble before layer 1 (preheat, home, a long dense bed-level mesh, nozzle wipe, second heat, filament load/purge). During the load the job clock ticks up while `remaining_time_sec` stays pinned and the head parks, and `filament_detected` reads 0 for the whole preamble, only flipping to 1 when loading finishes. None of that is a hang.

### 37. A settings patch that matches nothing exits 0

`build_3mf.py`'s patcher matched only scalar `"key": "value"`. The per-filament settings — cooling, temperatures — are **arrays**. Adding one to `patches` matched nothing, exited cleanly, and printed `patched project_settings: <key>` while shipping the template's value unchanged: a fix that existed only in the log. Array-valued keys now go through `array_patches`, and a scalar patch that matches nothing is a **hard failure**.

This is the general shape of the worst bugs in this repo. When you change something, **read the artifact back and prove it changed.** Never trust a log line.

---

## Print orientation

- **Bottom half**: rotate 180° around X so the silhouette face is on the build plate and the **pegs point up**. Prints flat, no supports.
- **Top half**: inner face (with peg holes) goes on the build plate. Prints flat, no supports.
- **Decoration** (raised spiral / emboss / etc.): flat side on the build plate.
- Settings: PLA or PETG, 0.12–0.16 mm layer height, 100% infill (these are tiny), no supports.

### 38. Blender 5.0 headless hangs unless you pass `--gpu-backend opengl`

`blender.exe -b --python build_<charm>.py` **hangs forever** in a headless/agent shell. Blender 5.0 defaults to the **Vulkan** backend and Vulkan context creation blocks when there is no desktop session. Always run:

```
blender.exe -b --gpu-backend opengl --python beads/<name>/build_<name>.py
```

The hang is easy to misread as a slow boolean solve. It isn't: the process sits at **~0.03 s CPU and ~18 MB working set** with **zero output**, having never reached your script. Check CPU time, not the log — Python's stdout is block-buffered when redirected, so a *working* run also shows an empty log for a long while. `blender --version` returns instantly even while `-b` hangs (it exits before app init), so a working `--version` proves nothing; probe with `-b --gpu-backend opengl --python-expr "print('OK')"`.

### 39. UNIONing decoration primitives: never let them share a face or a tangent

Building a raised decoration by UNIONing per-stroke solids (bars, end-caps, rings) is the natural approach and it *silently* produces non-manifold garbage — 1020 non-manifold edges on a 7-stroke sigil. The EXACT solver is fine with solids that cross transversally and bad at the two degenerate contacts, both of which this construction creates by default:

- **Coplanar faces.** If every bar and cap spans the same `z_lo..z_hi`, all their top and bottom faces are coplanar. Fix: union them **oversized in Z with a per-primitive jitter**, then let the final crop INTERSECT cut the exact slab. The cut planes then pass through solid material instead of lying tangent to a face.
- **Tangency.** A round end-cap of radius exactly `w/2` is precisely tangent to its bar's side faces — the same hazard as gotcha #9. Oversize the cap by ~2 µm so the surfaces cross.
- **Exact duplicates.** A connected stroke path (a sigil) shares endpoints, so consecutive segments each emit an *identical* cap at the joint. UNIONing a solid with a copy of itself is degenerate; emit each cap once.

Also drop the weld threshold for decorations: the pipeline's usual `remove_doubles` at **0.005 tears 0.8 mm strokes apart**. Boolean output is already welded — use `1e-5`.

Reference implementation with all four handled: `beads/glow-set/deco.py`.

**Build vs print orientation:** build scripts (`build_<charm>.py`) typically lay out the geometry in *build orientation* — the natural pose for boolean operations and inspection. The actual rotation to print orientation happens at export-time via `.claude/skills/bead-stl-export/export.py`, which has an `EXPORT_FLIP_X_DEG` dict that applies a deterministic per-part flip just before writing each STL. The live scene is unchanged; only the STL on disk is print-ready. This means the slicer should never need an auto-orient step.

### 40. The socket funnel and the peg chamfer both eat the ENGAGEMENT — measure it

A peg is not gripped along its whole height. `SOCKET_LEADIN` opens the socket
mouth into a 45-degree funnel, and `PEG_CHAMFER` tapers the peg tip; between
them they can consume most of a short peg. Measured on a real 1.2 mm peg with
`SOCKET_LEADIN = 0.4` and `PEG_CHAMFER = 0.35`, only **0.50 mm** ever sat at the
design clearance:

| depth into socket | socket r | peg r | radial gap |
|---|---|---|---|
| 0.0 mm (mating face) | 1.749 | — | — |
| 0.2 mm | 1.549 | 1.299 | 0.250 |
| 0.4 mm | 1.349 | 1.299 | **0.050** |
| 0.8 mm | 1.349 | 1.299 | **0.050** |
| 1.0 mm | 1.349 | 1.103 | 0.246 |

The bead read as "close, but too loose", and the instinct is to reach for
`PEG_CLEAR`. That is the wrong knob first: the clearance was fine, there was
just almost no length at which it applied. **`PEG_HEIGHT` is the first knob;
`PEG_CLEAR` is the second.**

**Solved on hardware, in two single-variable steps:**

| step | `PEG_HEIGHT` | `PEG_CLEAR` | engagement | result |
|---|---|---|---|---|
| start | 1.2 | 0.05 | 0.50 mm | plainly too loose |
| depth | **1.8** | 0.05 | **1.00 mm** | *snaps*, still won't hold |
| clearance | **1.8** | **0.02** | 1.00 mm | **perfect** |

**Use `PEG_HEIGHT = 1.8` and `PEG_CLEAR = 0.02`** alongside `SOCKET_LEADIN = 0.4`
and `PEG_CHAMFER = 0.35`.

The ordering is the whole lesson. At 0.50 mm engagement **no clearance value
would have rescued it**, because there was scarcely any length over which
clearance applied — so tuning `PEG_CLEAR` first is motion without information.
Move one at a time: had both changed together, the working fit would not have
said which change earned it, and the constants would not transfer to the next
silhouette.

**Target roughly 1.0 mm of full-diameter engagement.** Derive `PEG_HEIGHT` from
that rather than copying 1.8 — it must cover the engagement you want *plus*
`SOCKET_LEADIN` plus the chamfer's effective loss. A build with no socket
lead-in loses only the chamfer and reaches 1.0 mm at a shorter peg.

Never estimate this from the constants — the interaction is easy to get wrong by
2x. Cross-section both exported STLs and compare bore radius to peg radius at
the same seated height. `beads/glow-set/measure_fit.py` does exactly that and
prints the table above; run it after any change to peg or socket geometry, and
treat the printed **ENGAGEMENT** figure as the number that matters.

Deepening the peg has a second benefit: it moves the gripping band up out of the
first two squished layers, where the bore is least round (see #42).

### 41. `task_status: 1` means the GCODE RAN — it is not evidence a part exists

The printer will happily execute an entire job with a dry extruder and report
success: `task_status: 1`, `CurrentTicks == TotalTicks`, empty
`exception_status`. **Every check the SDCP API exposes is a check on the JOB,
and they all stay green when nothing comes out of the nozzle.** This has
produced phantom "successful" prints more than once.

**The check that actually decides it:** `raw._cc2.filament_detected` must read
**1 once layers are advancing** (`PrintInfo.CurrentLayer >= 1`). If layers are
climbing and that flag is 0, the extruder is dry — call `stop_print` rather than
let it paint air for the rest of the job.

**Do NOT gate on the idle reading.** An earlier version of this gotcha said to
require 1 while idle, and that rule is wrong: run `21da0e21` sat at idle
`filament_detected: 0`, loaded normally once the nozzle hit 210, and printed a
real part. Blocking on the idle value produces false negatives, because 0 at
idle just means nothing is parked at the sensor between jobs.

**The real discriminator is the SLOT.** Sorted that way the record is blunt:

| slot | runs | outcome |
|---|---|---|
| `T0` (black, FIRST slot) | `5e5a8e33`, `21da0e21` | 2/2 produced parts |
| `T1` (red, SECOND slot) | `17e2cd47`, `86fbb0e6` | printed nothing |
| `T1` (red) | `c0aa169a` | parts, but only after a hand-load |

`T1`'s auto-load is what fails. Every `T1` failure also happened to show idle-0,
which is how the idle flag looked causal when it was only riding along — a
correlation drawn from three runs that a fourth broke. **Prefer `T0` for
single-colour jobs**, and if a job must draw from `T1`, have the user hand-feed
that spool first.

The gcode is not the variable either: the *same file* both failed and succeeded,
and it carries a real load macro (`M6211 A1 L200 T<n>`). A file asking for
filament proves nothing, because that macro can fail silently.

**Confirming a print afterwards needs a human**, because the chamber camera
looks across the front lip and cannot see the plate centre — it reads empty
before and after a successful print. Ask specifically about the **purge line**:
no purge line means filament never reached the nozzle; a purge line with no part
means adhesion. See also #34 (slot numbering) and #35 (a `.3mf` is not a job).

### 42. The mating face is a tolerance surface — don't print it as layer 1

**Status: observed and diagnosed, not yet proven by a comparison print.**

The Top half currently prints mating-face-down, so the socket mouths — the one
set of features that has to hold a fit — are drawn in the first, most-squished
layers. The consequences show up under magnification and both hurt the snap fit:

- **The bore goes out of round.** The funnel's concentric steps form cleanly on
  one side while extrudate encroaches from the other, so clearance stops being
  uniform. A peg can be loose overall and still bind on one axis.
- **The face goes ridged**, with valleys between adjacent beads. Two halves then
  rest on high spots and never fully seat, stealing engagement on top of what
  #40 already spent.

The proof is available in any single print: the *Bottom* half's mating face is a
**top surface** and comes out visibly smoother than the Top's, same filament,
same run. Glitter-loaded filaments make it worse — they resolve small features
noticeably less well than plain PLA.

**Candidate fix:** flip the Top in `EXPORT_FLIP_X_DEG` so its mating face prints
as a top surface. The Top's outer face is the *back* of the bead, so nothing
cosmetic is lost by putting that against the plate, and the sockets become blind
holes drilled down from a smooth surface — which also removes the reason
`SOCKET_LEADIN` exists. This changes print orientation for every bead in a set,
so prove it on one part before adopting it.

---

## What the user supplies per charm

When you (the user) start a new charm session, you only need to talk about:

1. **The silhouette** — an SVG path, or a description detailed enough to commission/sketch one. Must be roughly bead-shaped: compact, with enough internal area to host a 10.5 mm NFC pocket plus 3 pegs without crowding.
2. **Where the string hole goes** — usually through the head / top of the silhouette, along the longer axis. Specify Y position in mm if the silhouette has a clear "head" region offset from center.
3. **Any non-default dimensions** — if you want a bigger bead, thicker halves, taller pegs, etc.
4. **Aesthetic / theme** — for naming, color choices in the .blend, any stylistic flourishes (engraved details, embossed text, color-swap regions, etc.). These are creative additions on top of the recipe.

Everything else (peg placement, NFC pocket position, gap-fill regions) is a derived decision — Claude should propose values based on the silhouette and ask for confirmation before building.

## Per-charm documentation

Every charm branch must ship a `beads/<name>/README.md` that captures the *intent* — the technical recipe is generic; the README is the only place future-Claude (or future-you) can recover *why this charm was built this way*. At minimum:

- **Source** — what input the silhouette came from (SVG path, image, sketch). If image-derived, the absolute path so the extraction can be re-run.
- **Why this charm exists** — what it's exercising or commemorating. Some charms exist to stress-test the pipeline with a new input format; some are gifts; some are commissioned. Knowing this informs how aggressively to refactor the build script later.
- **Key creative decisions and their tradeoffs** — every charm makes choices that aren't obvious from the build script's CONFIG block (multi-color regions vs flat, thinner profile, asymmetric layout, etc.). One row per decision, with the cost it imposed.
- **What's transferable / what's specific** — call out which parts of the build script generalize to future charms vs. which are tuned to this one's proportions. Keeps later charms from cargo-culting tuning constants.
- **Files** — pointer table to silhouette.svg, build script, .blend, stages, print/.

`beads/redaphid-portrait/README.md` is the reference example. Charm-branch builds should produce a README before the first commit lands, and update it whenever a creative decision changes (a region split is added, a dimension default is overridden, etc.).

### Print iteration log

Every charm that gets *physically printed* must also ship a `beads/<name>/PRINT_LOG.md` — append-only, newest at the top. Each entry: date, version, what was actually printed (parameters), failure mode (if any), parameter changes for the next attempt, lesson captured (one-liner that should propagate to the recipe / printability-check skill if it generalizes beyond this charm).

The README captures *intent*; the PRINT_LOG captures *what we learned by feeding plastic into the printer*. Across charms these logs become a corpus future-Claude can grep when starting a new build — "has anyone seen this failure mode before?"

`beads/redaphid-portrait/PRINT_LOG.md` is the reference example.

---

## Reference files in this repo

- `build_charm.py` — full working pipeline, parameterized at the top. Copy this and edit the CONFIG block for a new charm.
- `GUIDE.md` — long-form walkthrough with code snippets and a lessons-learned table.
- `wooli_silhouette.svg` — example input SVG (the Wooli mammoth).
- `models/` — example output STLs from a previous build.

---

## Quick-start for Claude in a new session

When the user opens a session referencing this prompt and a new silhouette:

1. Read `build_charm.py` to refresh the exact API calls and CONFIG schema.
2. Ask the user for: SVG path (or silhouette description), string-hole Y position, any dimension overrides.
3. Propose peg positions and NFC pocket center based on the silhouette's bounding box and interior — show the user before building.
4. Copy `build_charm.py` to a new file (e.g. `build_<charm>.py`), update the CONFIG block, run via Blender background mode.
5. Verify with the built-in raycast checks; iterate on peg positions if any verification fails.
6. Export both STLs; render a quick preview if useful.

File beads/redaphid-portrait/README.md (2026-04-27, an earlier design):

# redaphid-portrait — cartoon self-portrait NFC charm

A two-half snap-fit NFC bead built from a glowy, neon-outlined screenshot of a cartoon self-portrait. **First charm in this repo built from a raster image instead of a hand-drawn SVG.**

## Source

`C:\Users\hypnodroid\Pictures\Screenshots\Screenshot 2026-04-25 235837.png` — a soft pink-glow portrait with a bumpy crown of hair, two drooping ear-flaps on the sides, a chin/neck protrusion, and two warm-orange glowing eyes inside a dark plum head. The user described it as "a cartoonish version of me".

## Why this charm exists

To stress-test the generic NFC bead pipeline with a SOURCE FORMAT it hadn't supported before — a raster screenshot with no clean vector input. Earlier charms in this repo (Wooli mammoth, Rezz spiral) all started from SVG paths the user could hand-tune. This one tested whether the recipe could absorb an image-derived silhouette + a multi-color region split, end-to-end.

The pipeline that came out of this iteration is the contribution. The charm itself is a side-effect.

## The pipeline that came out of this

`extract_silhouette.py` is a host-side Python script that does, in order:

1. **Gaussian blur** the screenshot to denoise.
2. **Luminance-threshold** to a binary figure mask (background ≈ 0, figure ≈ 25+).
3. **Fill holes + keep largest component** to recover the silhouette mask.
4. **Marching-squares contour trace** on the silhouette mask.
5. **Fourier-descriptor smoothing** to drop high-freq wobble — emits a clean polygon as `silhouette.svg`.
6. **Eye detection** by `R − B` chroma channel — pink outline has high B (cancels out), warm orange eyes are R-dominant. Centroid + radius per blob → `<circle>` elements in `silhouette.svg`.
7. **Hair-shape detection** geometrically: above an eyebrow line (anchored to eye Y) + far from the central column (anchored to eye spacing). Emits `hair.svg`. Chin/neck below the jawline stays out → it's automatically face/skin.

Pipeline borrowed and stripped down from [`laser-cube-driver`](D:\Projects\laser-cube-driver) — the same Sobel + flood-fill + Moore-boundary + Fourier-smooth chain it uses to feed a LaserCube projector. That repo (`shader-to-laser-path` / `ContourTracer.js`) was the reference; this script is the host-Python translation.

Then `build_redaphid.py` imports both SVGs into Blender and runs the canonical NFC-bead recipe: scale to 25 mm wide, extrude to 4 mm, drill the string hole, box-cut split, NFC pocket on Bottom, peg/socket pair, hair slab on top of Top, eye dots on top of that.

## Key creative decisions (and tradeoffs)

| Decision | Why | Cost |
|---|---|---|
| Thinner than default (4 mm vs 5 mm) | Charm reads less chunky on a kandi bracelet | `PEG_HEIGHT` drops to 1.0 mm to keep ≥ 0.5 mm wall above sockets |
| Multi-color regions: body / hair / eyes | Centauri Carbon 2 has multi-filament; flatness is a waste of it | Adds a `Hair` STL on top of the canonical 3 — required updating the export skill + 3MF builder |
| Real face/hair contour, not an ellipse | An ellipse-cutout face looked like a Picasso decomposition; the user wanted the haircut to read as hair | Extra extraction stage; needs eye positions as anchors |
| Hair sits ON TOP of full-silhouette show face (additive) instead of cutting the face out (subtractive) | "Hair drapes over the face" is the right mental model; chin/neck stays as skin automatically | Requires the SVG-frame fix (gotcha #15) |
| String hole y=7.5 (low in hair band, not at top) | Load-bearing wall ≥ 2 mm; the bead hangs off a bracelet | Hair extraction has to leave a wider hair band for the hole to fit cleanly |
| Pegs on Bottom (recipe default), not Top | Pegs on Top + show-face decoration is unprintable (cantilever, can't flip) | None — this was a wrong turn we backed out of (gotcha #14) |

## What's transferable to future charms

- **The `extract_silhouette.py` pipeline** is mostly reusable for any glowy-outlined source image. The eye-detection step is specific to "warm dot inside a cool body"; the hair-detection step is specific to characters where eye position is a useful anchor. Other characters may need different region-extractors (a halo? a hat? an animal's ear vs leg?).
- **The "Hair as additive overlay on full show face"** pattern generalizes — anywhere you want a multi-color charm where one color is "the body" and another is a draped/raised region.
- **Gotchas #13–#20** in `prompts/nfc-bead/prompt.md` are all generic — they applied here but will trip up any charm with a centered-mesh build pipeline.

## What's specific to this charm

- The HAIR_*_FACTOR knobs in `extract_silhouette.py` are tuned for THIS portrait's proportions (eye spacing, head height). Other portraits with different proportions will need re-tuning.
- The eye R-B threshold of 30 was set by sampling pixels in this specific screenshot. A different rendering style (cooler eyes, or eyes that aren't warm-dominant) would miss.
- `silhouette.svg` and `hair.svg` are committed because they're the actual derived geometry — they're the contract between the extraction script and the build script. If the source image changes, regenerate them.

## Files

- `silhouette.svg` — outer-outline contour + eye `<circle>` elements
- `hair.svg` — haircut-shape contour (top hair + side ear-flaps)
- `extract_silhouette.py` — screenshot → SVGs (uses scipy + skimage)
- `build_redaphid.py` — SVGs → Blender → STLs (CONFIG block at top)
- `redaphid-portrait.blend` — working scene snapshot, refreshed on every successful build
- `stages/` — milestone `.blend` snapshots
- `print/` — STLs + 3MF (drag `redaphid-portrait.3mf` into Elegoo Slicer)

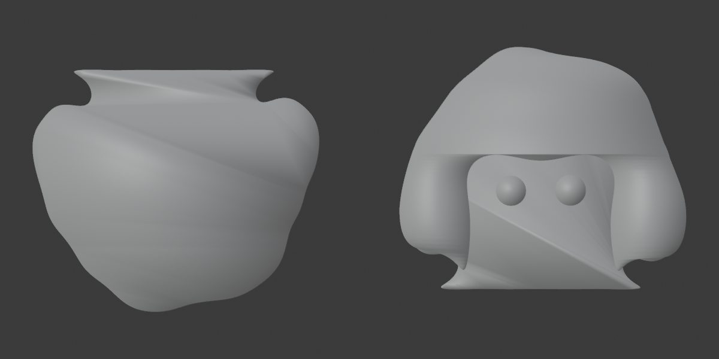
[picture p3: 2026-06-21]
beads/redaphid-portrait-v2/preview.png

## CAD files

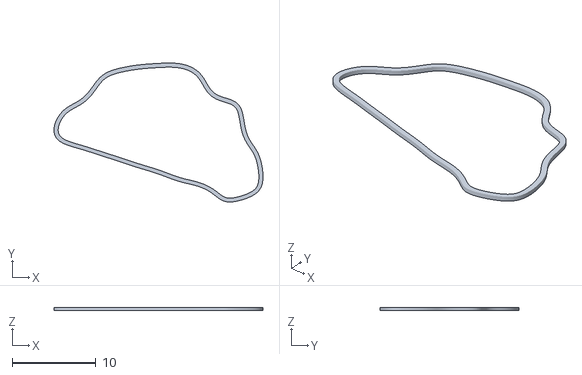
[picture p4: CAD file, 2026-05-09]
beads/filibertos-taco/print/blocks/DecorationShellOutline.stl
24.9 x 16.6 x 0.4

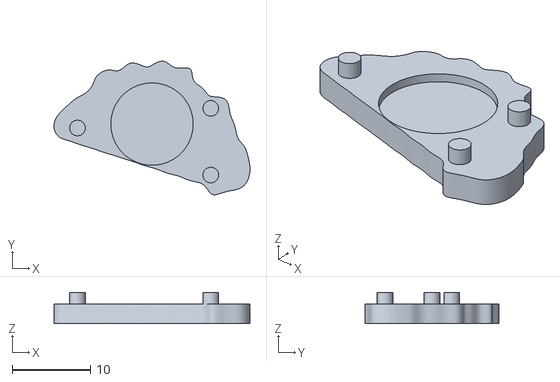
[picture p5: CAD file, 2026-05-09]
beads/filibertos-taco/print/Bottom.stl
25.0 x 17.0 x 4.00

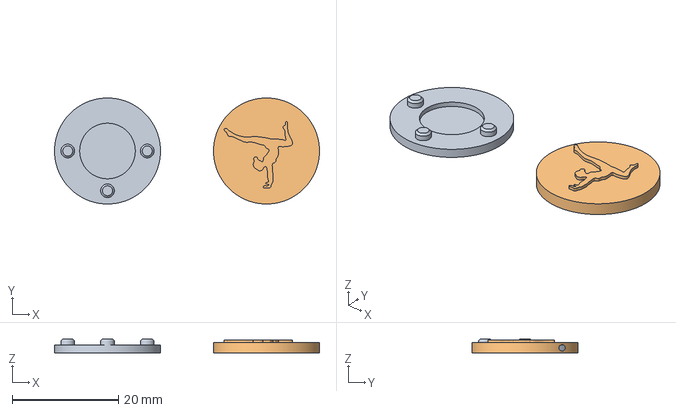
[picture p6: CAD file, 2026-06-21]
beads/gymnast-medallion/print/gymnast_medallion.3mf
50.0 x 20.0 x 2.70 mm
Bottom
Top_with_Decoration

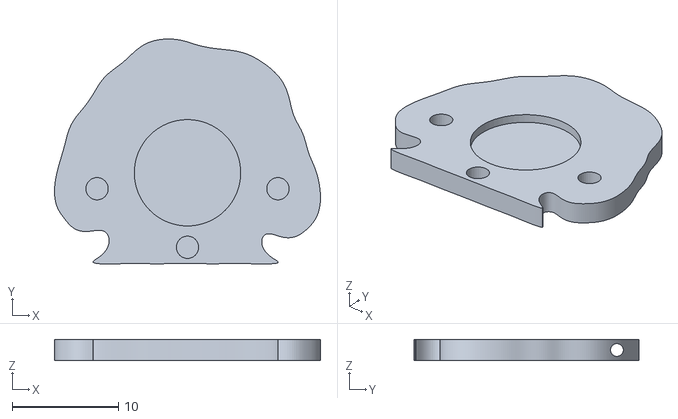
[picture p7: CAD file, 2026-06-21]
beads/redaphid-portrait-v2/print/Bottom.stl
25.0 x 21.1 x 2.00

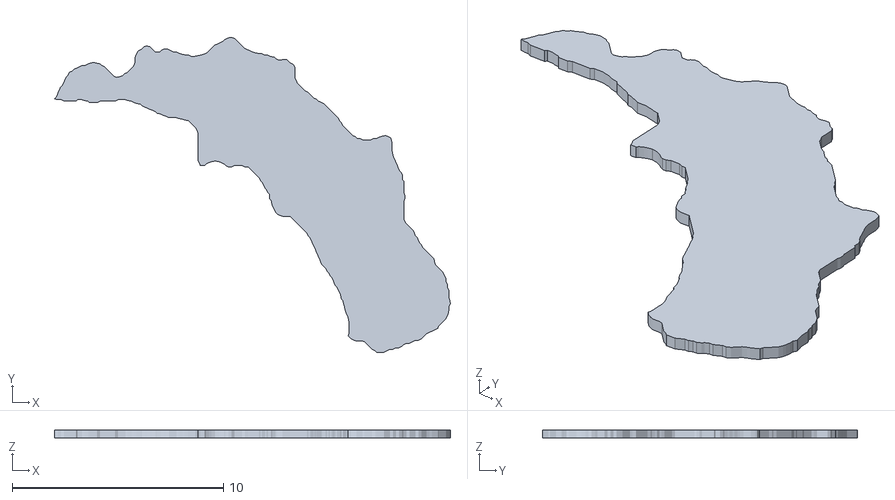
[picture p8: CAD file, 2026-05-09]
beads/filibertos-taco/print/blocks/DecorationFilling.stl
18.8 x 14.9 x 0.4

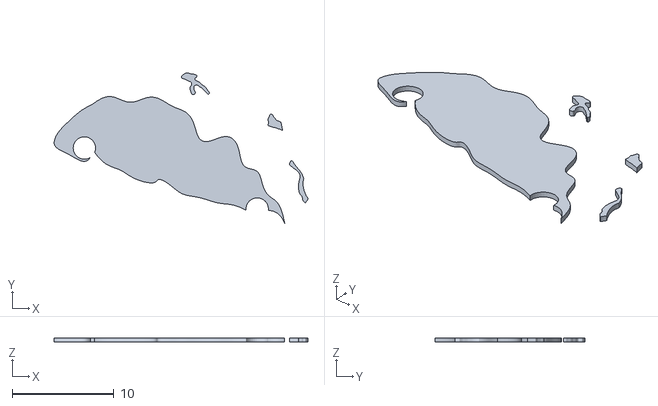
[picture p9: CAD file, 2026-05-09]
beads/filibertos-taco/print/DecorationShellDark.stl
25.0 x 14.8 x 0.4

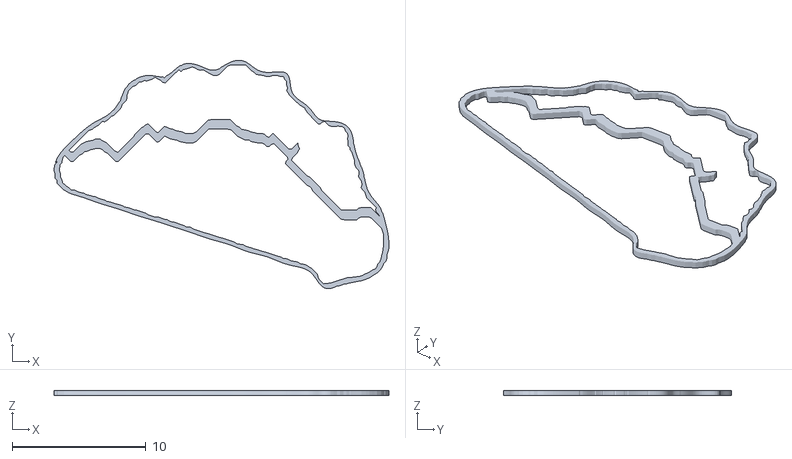
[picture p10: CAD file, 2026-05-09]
beads/filibertos-taco/print/neon/Decoration.stl
25.0 x 17.0 x 0.4

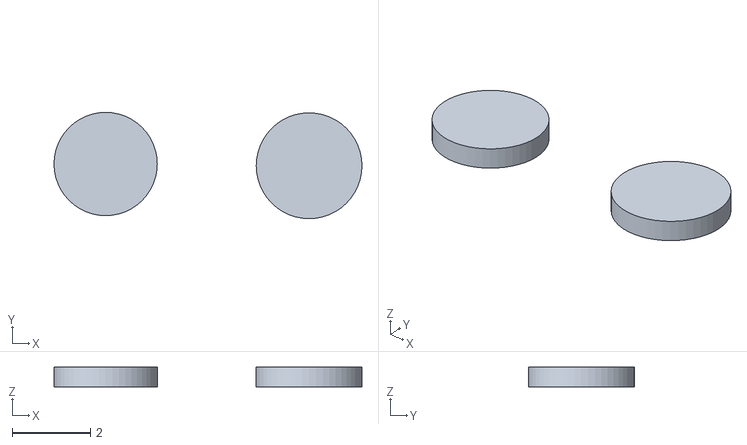
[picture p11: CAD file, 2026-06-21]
beads/redaphid-portrait-v2/print/Decoration.stl
7.85 x 2.71 x 0.5

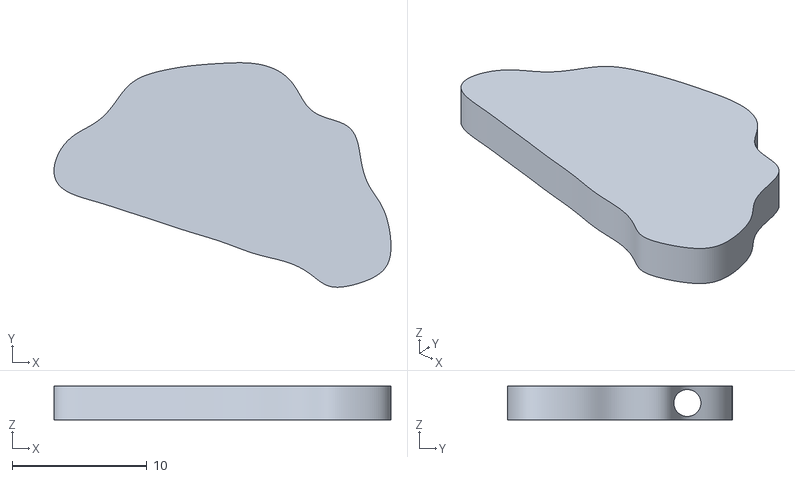
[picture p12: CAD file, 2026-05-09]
beads/filibertos-taco/print/blocks/Top.stl
25.0 x 16.7 x 2.50

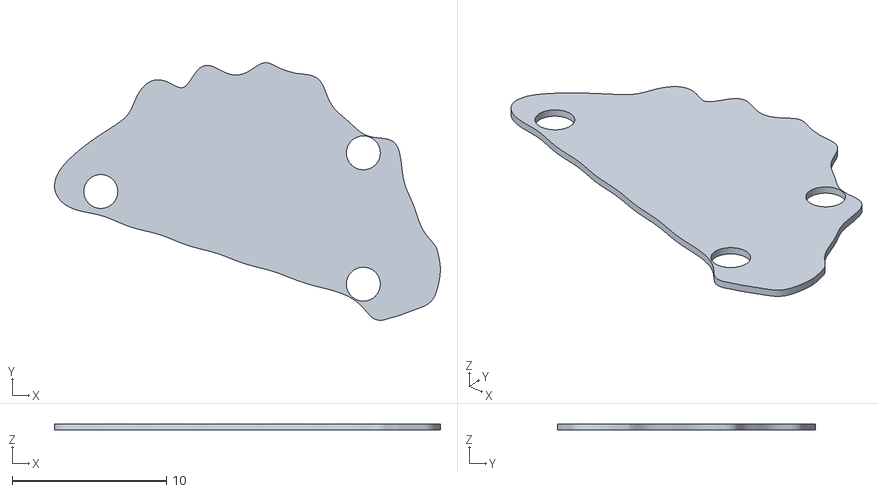
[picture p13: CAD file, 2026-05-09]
beads/filibertos-taco/print/DecorationOutline.stl
25.0 x 16.7 x 0.4

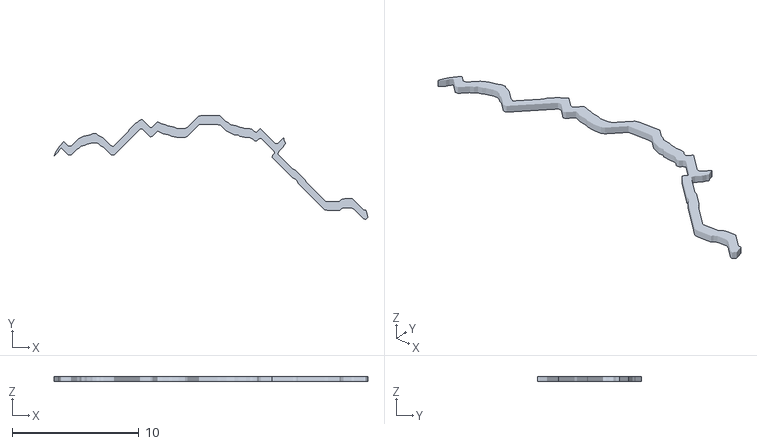
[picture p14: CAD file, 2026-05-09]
beads/filibertos-taco/print/neon/DecorationFillingLine.stl
24.7 x 8.20 x 0.4

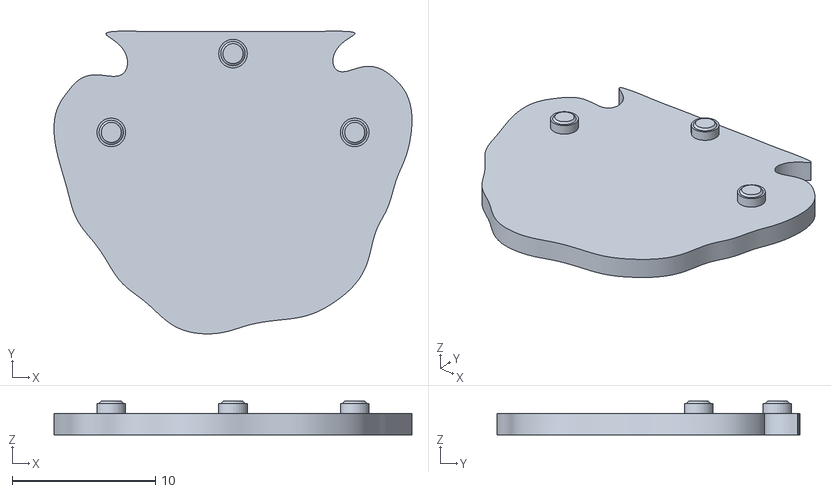
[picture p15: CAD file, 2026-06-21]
beads/redaphid-portrait-v2/print/Top.stl
25.0 x 21.1 x 2.35

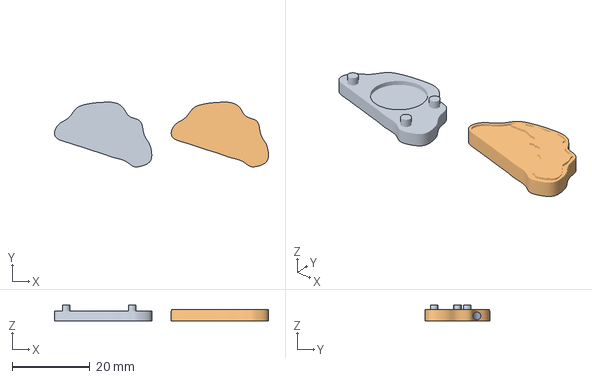
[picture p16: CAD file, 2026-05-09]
beads/filibertos-taco/print/blocks/filibertos-taco-blocks.3mf
55.0 x 16.7 x 4.00 mm
Bottom
Top_with_decorations

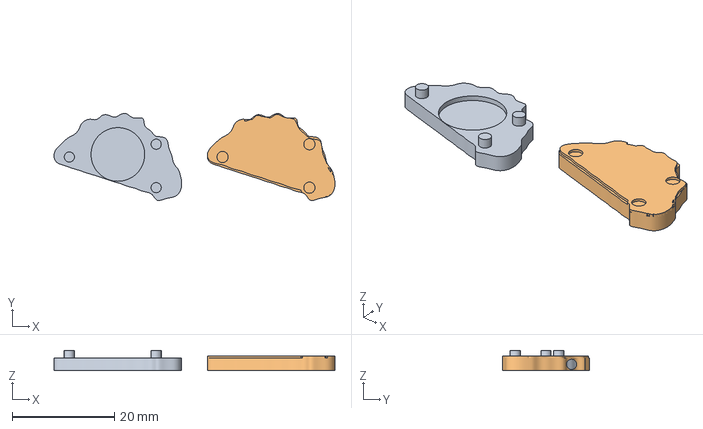
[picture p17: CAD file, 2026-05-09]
beads/filibertos-taco/print/filibertos-taco.3mf
55.0 x 17.0 x 4.00 mm
Bottom
Top_with_Decoration

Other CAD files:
beads/filibertos-taco/print/neon/Bottom.stl
beads/filibertos-taco/print/neon/DecorationSilhouette.stl
beads/redaphid-portrait-v2/print/Hair.stl
beads/filibertos-taco/print/blocks/DecorationInteriorDetail.stl
beads/filibertos-taco/print/Decoration.stl
beads/filibertos-taco/print/DecorationLettuceDark.stl
beads/filibertos-taco/print/DecorationLettuceLight.stl
beads/filibertos-taco/print/Top.stl
beads/filibertos-taco/print/blocks/Bottom.stl
beads/filibertos-taco/print/blocks/DecorationLettuceSeparator.stl
beads/filibertos-taco/print/filibertos-taco_charm.blend
beads/filibertos-taco/print/neon/Top.stl
beads/filibertos-taco/print/neon/filibertos-taco-neon.3mf
beads/filibertos-taco/stages/01_built_verified.blend
beads/filibertos-taco/stages/02_v3_4color.blend
beads/filibertos-taco/stages/03_v4_neon.blend
beads/filibertos-taco/stages/04_v4b_neon_continuous.blend
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

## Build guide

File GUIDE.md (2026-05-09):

# Guide: SVG Logo to 3D-Printable Snap-Fit Charm

A step-by-step reference for turning any 2D logo SVG into a two-half 3D-printable charm with friction-fit pegs and an NFC pocket. Written from hard-won experience building the Wooli mammoth charm.

## Pipeline Overview

```
SVG silhouette
  → Import into Blender as 2D curve
  → Convert to mesh, scale to target size
  → Fill any interior gaps that interfere with features
  → Extrude to desired thickness
  → Boolean DIFFERENCE for string hole
  → Box-cut INTERSECT to split into halves
  → Boolean DIFFERENCE for NFC pocket (bottom)
  → Boolean DIFFERENCE for peg holes (top, POST-split)
  → Boolean UNION for pegs (bottom)
  → Flip bottom for printing, export STLs
```

## Step-by-Step

### 1. SVG Import and Scaling

```python
bpy.ops.import_curve.svg(filepath=SVG_PATH)
# Join all curves, set 2D fill
curve_obj.data.dimensions = '2D'
curve_obj.data.fill_mode = 'BOTH'
curve_obj.data.resolution_u = 64  # smooth curves
# Convert to mesh
bpy.ops.object.convert(target='MESH')
# Scale: SVG imports in meters, scale to target mm
```

**Key point**: `resolution_u = 64` gives smooth curves. Lower values produce visible faceting on curves.

### 2. Handling Interior Holes in the Silhouette

Many logos have interior through-holes (e.g., the space inside a letter "O", or in our case, the gap between the mammoth's trunk and body). These can interfere with features like NFC pockets.

**To fill a specific hole** (while preserving others):
```python
# In edit mode, select boundary edges of the target hole by position
for e in bm.edges:
    if e.is_boundary:
        if (both verts within the hole's coordinate range):
            e.select = True
bpy.ops.mesh.fill()
```

**What NOT to do**:
- Don't add an overlapping rectangle in the SVG — it creates a separate boundary that doesn't merge with the hole
- Don't use `bpy.ops.mesh.fill()` on ALL boundary edges — it fills every hole including ones you want to keep
- Don't use Solidify modifier with interior holes — it creates topology issues. Use Extrude instead.

### 3. Extrude vs Solidify

**Use Extrude**, not Solidify, when your 2D profile has interior holes (like the leg gap):

```python
bpy.ops.mesh.select_all(action='SELECT')
bpy.ops.mesh.extrude_region_move(
    TRANSFORM_OT_translate={"value": (0, 0, THICKNESS)}
)
```

Solidify modifier can produce bad topology around interior boundaries. Extrude gives a clean result.

### 4. Boolean Operations — The EXACT Solver

Always use `solver = 'EXACT'` for boolean operations. The FAST solver produces non-manifold geometry.

After every boolean, clean up:
```python
bpy.ops.mesh.remove_doubles(threshold=0.005)  # tight threshold!
bpy.ops.mesh.normals_make_consistent(inside=False)
```

**Critical**: Use a tight `remove_doubles` threshold (0.005mm). Larger values (0.02+) can destroy small features or collapse geometry.

### 5. Splitting into Halves

Use a box-cut boolean INTERSECT at the midpoint:

```python
# Create a box covering the bottom half of the bead
bpy.ops.mesh.primitive_cube_add(size=1, location=(0, 0, z_min + half_height/2))
box.scale = (200, 200, half_height)
# INTERSECT keeps only the overlap
b = obj.modifiers.new(name="Cut", type='BOOLEAN')
b.operation = 'INTERSECT'
b.object = box
b.solver = 'EXACT'
```

### 6. Peg Holes — The Coplanarity Trap

**CRITICAL**: Cut peg holes AFTER splitting, not before.

If you cut peg holes in the full bead before splitting, the box-cut INTERSECT boolean at the split plane (z=0) is coplanar with the peg hole bottoms. The EXACT solver loses the holes — they get sealed shut.

**Solution**: Split first, then cut peg holes into the top half with cutters that extend **1mm below the inner face**:

```python
cutter_bottom = inner_face_z - 1.0  # extend past the face
cutter_top = inner_face_z + PEG_HEIGHT + 0.3
```

This ensures the boolean cutter fully penetrates the inner face rather than being coplanar with it.

### 7. Adding Pegs — Boolean UNION, Not Mesh Join

**Use boolean UNION** to add pegs to the bottom half:

```python
b = bottom.modifiers.new(name="Peg", type='BOOLEAN')
b.operation = 'UNION'
b.object = peg_cylinder
b.solver = 'EXACT'
```

**Do NOT use mesh join** (`bpy.ops.object.join()`). Mesh join creates 1000+ non-manifold edges where the peg cylinder meets the flat inner face, because overlapping coplanar faces don't merge cleanly.

### 8. Verifying Features with Raycast

After building, verify holes are actually open:

```python
from mathutils import Vector
depsgraph = bpy.context.evaluated_depsgraph_get()
eval_obj = obj.evaluated_get(depsgraph)
# Cast ray through where the hole should be
result = eval_obj.ray_cast(origin, direction)
if result[0]:
    print(f"BLOCKED at z={result[1].z}")  # hole is sealed
else:
    print("OPEN")  # hole goes through
```

### 9. Print Orientation

- **Bottom half**: Flip 180° around X so the mammoth face is on the build plate and pegs face up
- **Top half**: Inner face (with peg holes) is already at the bottom — prints flat on build plate

## Lessons Learned

| Issue | Cause | Fix |
|---|---|-----|
| Voxel remesh seals small holes | Remesh resolution too coarse for 2mm holes | Don't use voxel remesh when holes must be preserved |
| Pre-split peg holes vanish | Boolean INTERSECT at coplanar split plane | Cut peg holes AFTER splitting |
| Peg hole cutters leave thin membrane | Cutter starts at z=0.05 (nearly coplanar) | Extend cutters 1mm BELOW inner face |
| Mesh join creates non-manifold pegs | Overlapping coplanar faces from join | Use boolean UNION instead |
| `remove_doubles(0.05)` destroys mesh | Threshold too large for small features | Use 0.005mm threshold |
| NFC pocket intersects trunk gap | Pocket placed over interior through-hole | Fill the gap in the mesh, or move the pocket |
| SVG rectangle doesn't fill hole | Separate path creates separate boundary | Select and fill the hole boundary in mesh edit mode |
| Solidify breaks interior holes | Solidify modifier produces bad topology | Use extrude instead |
| String hole splits a thin top wall | `HOLE_Y` placed in a narrow protrusion (hair ridge, ear, tip) | Drop hole down into the wider head/forehead — need ≥ 2.5 mm of solid silhouette above the hole |
| String hole only carves Top half (Bottom solid) | `location.z = THICKNESS/2` on a centered-mesh pipeline puts the cylinder at the TOP face, not the middle | Compute `z_mid = (min(zs)+max(zs))/2` from live verts and drill there. See prompt.md gotcha #13 |
| Slicer flags Top assembly as cantilever | Pegs hung off Top instead of Bottom; the body is suspended on three thin pillars | Pegs MUST be on Bottom for any charm with show-face decoration on Top — flipping Top to put pegs up would point the hair into the build plate. See gotcha #14 |
| Imported subset SVG (e.g. `hair.svg`) lands off-center | `origin_set BOUNDS` re-centers on the path bbox, not the viewBox center the silhouette is anchored to | Parse viewBox dims + path bbox, set `obj.location = (subset_cx − vbox_cx, vbox_cy − subset_cy, 0)` (Y-flipped). See gotcha #15 |
| Bottom STL lands silhouette-up after export | Export skill's default 180° X-flip on Bottom assumes a flipped-build live scene; centered-mesh builds are already in print orientation | Set `bpy.context.scene["nfc_export_flip_override"]` to `{"Bottom": 0, ...}` before running the export. See gotcha #16 |
| MCP socket dies after `read_factory_settings` | Factory reset unregisters the BlenderMCP addon | Don't factory-reset; delete objects explicitly. Or relaunch via `tools/launch.ps1`. See gotcha #17 |
| `if __name__ == "__main__"` block doesn't run | `exec(open(...).read())` keeps the calling module's `__name__` | Pass `ns = {"__name__": "__main__"}` to `exec(script, ns)`, or call `main()` directly. See gotcha #18 |
| Color extraction loses saturation under blur | `gaussian_filter(rgb, sigma=4)` blurs the channel axis too, collapsing chrominance | Use `sigma=(blur, blur, 0)` to leave channels untouched. See gotcha #19 |
| `FullBead.001..N` accumulating across rebuilds | Re-running the build doesn't clean intermediate objects | Wipe `FullBead*` at the top of the build, or `bpy.data.objects.remove` explicitly. See gotcha #20 |
| NFC pocket clips past silhouette boundary on one side | No perimeter check on the NFC — only its center was validated | Add 16-point raycast around the pocket boundary. See gotcha #24 |
| Multi-region SVGs land at different scales/positions | Each SVG auto-fit to its own path bbox; bboxes differ between regions | Use the polygon-manifest pipeline (`regions.json` + `polygons_to_mesh()`). See gotcha #25 |
| Decoration shows visible peg-socket circles | Cropper was made from a duplicate of Top; peg sockets propagate as holes through the decoration | Build cropper from a fresh `silhouette.svg` extrusion via `build_silhouette_cropper()`. See gotcha #26 |
| Multi-color decoration layer disappears or shows wrong filament in slicer | Z-step between decoration layers below slicer layer height (0.16mm); slicer can't disambiguate | Set `DECO_LAYER_STEP ≥ 0.16mm` (0.20mm for safety). See gotcha #27 |
| 3MF imports as "too small" / one half upside-down | Each part added as a separate top-level `<object>` with own `<item>` confuses the slicer | Wrap Top + decorations in a single `ComponentsObject` with one build item. See gotcha #28 |

## Multi-color decoration workflow

For charms with several colored regions on the show face (cartoon illustrations, logos, multi-filament block prints), follow this pipeline. It avoids the SVG-round-trip pitfalls and produces consistent inter-region alignment. Reference: `beads/filibertos-taco/`.

### 1. Source-image extraction (k-means clustering)

If your input is a colored bitmap (JPG/PNG illustration), use k-means on FG pixels to identify color clusters, then map clusters to named regions via predicate functions. See `beads/filibertos-taco/extract_regions.py`.

### 2. Polygon manifest (`regions.json`)

Emit each region's polygon vertices in **shared mm coordinates** (origin = silhouette bbox center, +Y up). Use the dict shape `{outer: [(x,y),...], holes: [[(x,y),...], ...]}` so ring polygons (e.g. silhouette outline) carry both the outer and inner contours.

For ring polygons specifically: build the outer + inner contours with **shapely's `.buffer(-N)`** of the silhouette polygon. This guarantees the outer edge of the ring matches the silhouette.svg used for the bead body.

### 3. Build → `polygons_to_mesh()`

Consume the manifest and call `polygons_to_mesh(polygons, name, z=...)` (provided in `build_charm.py.example`). It handles simple polygons, ring polygons (via `bridge_loops`), and multi-hole polygons (via `triangle_fill`).

### 4. Crop with `build_silhouette_cropper()`

Always build the decoration cropper from a fresh `silhouette.svg` import — not a duplicate of Top, which propagates peg-socket holes through the decoration. Helper in `build_charm.py.example`.

### 5. Z-stack with ≥0.16mm step

Each decoration layer needs `DECO_LAYER_STEP ≥ slicer layer height` so the slicer assigns each unambiguously to its own filament. Order matters in the build's iteration: things at higher Z OCCLUDE things below — put the visually dominant decoration last.

### 6. 3MF bundling

Wrap Top + every Decoration into a single `ComponentsObject` with **one build item**; Bottom on its own build item with a plate offset. See `tools/make_3mf.py` for the canonical Top + Hair + Decoration set; mirror its structure for charms with more decoration layers (e.g. `beads/filibertos-taco/bundle_3mf.py`).

## Dimensions Reference (Wooli Charm)

| Feature | Value |
|---|---|
| Overall width | 25mm |
| Overall height | ~19.7mm |
| Thickness | 5mm (2.5mm per half) |
| String hole | 2mm diameter, X-axis through head |
| NFC pocket | 10.5mm diameter, 0.8mm deep |
| Peg diameter | 1.5mm |
| Peg height | 1.5mm |
| Peg hole clearance | 0.1mm per side |
| Peg positions | (-4, 6), (7, -3), (5, -7) |

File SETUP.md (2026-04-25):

# Setup — Blender MCP for live charm building

This is the one-time setup so Claude Code can drive Blender live (you watch geometry build in the viewport and can steer mid-build). Headless `blender --background --python <script>.py` works without any of this — only set up the MCP if you want the live workflow.

The repo is platform-agnostic, but the prerequisites differ by OS. Windows is the most thoroughly tested path; macOS / Linux are sketched at the bottom.

## Prerequisites

You need three things, regardless of OS:

1. **Blender 4.x or newer** (tested on 5.0.1)
2. **`uvx`** (from [Astral `uv`](https://astral.sh/uv)) — runs the Blender MCP bridge
3. **The Blender MCP addon** — bundled in this repo at `.claude/skills/nfc-bead/blender_mcp_addon.py` (sourced from [ahujasid/blender-mcp](https://github.com/ahujasid/blender-mcp))

The repo's `.mcp.json` is already wired to spawn `uvx blender-mcp` when Claude Code starts in this directory. So once Blender + `uvx` exist and the addon is enabled, the bridge connects automatically on Claude Code startup.

## Windows setup

### One-time installs

```powershell
winget install BlenderFoundation.Blender    # if not already installed
winget install astral-sh.uv                 # provides uv + uvx
```

After installing `uv`, **open a fresh terminal** so `PATH` picks up the new binary. The freshly installed `uvx.exe` lives under `%LOCALAPPDATA%\Microsoft\WinGet\Packages\astral-sh.uv_*\` and is added to user `PATH` by the installer.

If Blender lives somewhere non-standard (e.g. a portable install under `D:\tools\blender`), it doesn't need to be on `PATH` for the MCP — but for headless runs you'll invoke its full path directly.

### Install the Blender addon (one-time)

1. Open Blender
2. **Edit → Preferences → Add-ons**
3. Top-right dropdown → **Install from Disk...** *(in older Blender, just an "Install" button)*
4. Pick `<repo>\.claude\skills\nfc-bead\blender_mcp_addon.py`
5. In the addon list, type `MCP` in the search box → tick the checkbox next to **Interface: Blender MCP**
6. Close Preferences

### Per-session: bring up the bridge

**Fast path (recommended — uses the bundled bootstrap):**

```powershell
.\tools\launch.ps1                # opens Blender pre-wired for the rezz bead
.\tools\launch.ps1 -Bead wooli    # different bead's .blend
.\tools\launch.ps1 -BlendFile foo.blend
```

`tools/launch.ps1` calls Blender with `--python tools/blender_bootstrap.py`, which idempotently:
1. Copies the bundled `blender_mcp_addon.py` into Blender's user-addons directory if missing/stale
2. Enables the addon (`addon_utils.enable(..., persistent=True)`)
3. Saves user preferences so the enable state survives a Blender crash
4. Starts the MCP socket server

So all you need to do per session is run the launcher and then `/mcp` here.

**Manual path (if you'd rather click):**

1. Open Blender
2. In the 3D viewport press **N** to open the right sidebar
3. Click the **BlenderMCP** tab (vertical text on the sidebar's edge)
4. Click **Connect to Claude** — this starts a socket inside Blender on port 9876

Inside Claude Code (either path):

5. Run `/mcp` — the `blender` server should show **connected**. On a fresh Claude Code session, the `.mcp.json` spawn happens at startup; on an existing session, `/mcp` retries the connection.

If `/mcp` keeps reporting **Failed to reconnect to blender**, it means `uvx blender-mcp` is running but can't reach the addon's socket. Verify the addon is enabled and the server is started.

## macOS / Linux

Same shape, different installers. Use Homebrew / the package manager / the distro repo for Blender, then `curl -LsSf https://astral.sh/uv/install.sh | sh` for `uv`. The addon install and per-session bring-up steps are identical.

## Why a Claude Code restart is needed

Claude Code reads `.mcp.json` only at startup. Even if you add the addon to a running Blender mid-session, the `uvx blender-mcp` bridge process must already be running, which only happens at Claude Code startup. So the order is always: **install addon → click "Connect to Claude" in Blender → restart Claude Code**.

## Stopping

- Click **Disconnect** in the BlenderMCP sidebar tab in Blender, or close Blender
- The `uvx blender-mcp` bridge process stops when Claude Code exits

## Troubleshooting

| Symptom | Likely cause | Fix |
|---|---|---|
| `/mcp` shows blender failed | Addon not enabled, or "Connect to Claude" not clicked | Enable addon + click connect, then `/mcp` to retry |
| `uvx` not found | Fresh terminal hasn't picked up new PATH | Open a new shell after installing `uv` |
| Addon doesn't appear in install list | Blender filters by description text | Search literally `MCP` — display name is "Interface: Blender MCP" |
| Port 9876 in use | Another process holds it (or a stale Blender) | Kill the holder, or change the port in the BlenderMCP sidebar |
| MCP works but tools missing in Claude | `/mcp` shows blender connected but no `mcp__blender__*` tools | Restart Claude Code — tool schemas register at startup |

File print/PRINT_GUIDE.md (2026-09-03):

# Print Guide — Multi-color NFC Bead on Centauri Carbon 2

End-to-end workflow for printing a multi-color NFC bead (default sizing: 20 mm kandi-bracelet) on a Centauri Carbon 2 with Elegoo Slicer. Default colors are red body + black decoration; override per charm in the build script.

The Centauri Carbon 2 is **multi-filament** — auto-feeds between filaments mid-print. **Do NOT use M600 / manual filament-swap workflows on this hardware.** The slicer assigns filaments per part and the printer handles every transition automatically.

## The fast path — slicer-ready 3MF

The recommended workflow generates a single `.3mf` file with everything pre-arranged. **One drag into Elegoo Slicer and you can press slice.**

```sh
# 1. (in Blender) export STLs from the live scene
exec(open(r"<repo>/.claude/skills/bead-stl-export/export.py").read())

# 2. (host shell) verify alignment + manifold
uv run nfc-verify-stls

# 3. (host shell) build the slicer-ready 3MF
uv run nfc-build-3mf
```

That writes `tmp/latest/bead_multicolor.3mf` with:

- **`Bottom`** as one object on the plate, assigned to **Filament 2** (red body)
- **`Top` + `Decoration`** as a single multi-part object on the plate; **`Top`** on Filament 2 (red), **`Decoration`** on Filament 1 (black). Already merged — no manual "Combine into one object" step needed.
- **`brim_type=auto_brim`, `brim_width=5`, `raft_layers=0`** patched into the project settings.
  **This guide used to say `no_brim`, and that was wrong** — a 3MF that reached the plate
  without a brim smeared its first layer, and the 3MF that printed cleanly carried
  `auto_brim` at 5 mm. A missing printer profile is the usual way the brim goes absent
  (see recipe gotcha #33). Keep the brim; it is the adhesion fix, not clutter.
- **Centauri Carbon 2 printer profile** preserved from the reference 3MF in `tmp/latest/slicer_template/` — process preset, machine config, filament slots all match what's on your slicer.

Drag `tmp/latest/bead_multicolor.3mf` into Elegoo Slicer, verify the layer preview shows red body + black spiral at the right Z, and press slice.

## Printing autonomously over the MCP (no GUI)

The whole path is scriptable — this box has a **headless slicer** at
`D:	ools\elegooslicer\elegoo-slicer.exe` (note the hyphen; searching for
`ElegooSlicer.exe` finds nothing and two sessions wrongly concluded there was no
slicer here). It is a GUI-subsystem binary that prints nothing to the console,
so judge it by the artifact it writes, not by its output:

```sh
# 3MF -> gcode; emits plate_1.gcode into the output dir
/d/tools/elegooslicer/elegoo-slicer.exe --slice 0     --outputdir "D:\path	o\out" "D:\path	o\project.3mf"

# the MCP server runs in a container and cannot see host paths -
# stage the file into it first, then upload by its CONTAINER path
docker cp "D:\path	o\out\plate_1.gcode" centauri-mcp:/tmp/job.gcode
```

Then `upload_file(local_path="/tmp/job.gcode")` and `start_print(...)`.

### Pre-flight — do not skip these, each one has burned a real print

1. **`filament_detected` must read 1 once layers are advancing.** A dry extruder
   runs the whole job and still reports `task_status: 1` — recipe gotcha #41,
   two phantom prints so far. It reads 0 *legitimately* through preheat, bed
   mesh, nozzle wipe and load, so poll until `CurrentLayer >= 1` and judge it
   there; if layers are climbing with the flag at 0, `stop_print`.
   **Do not gate on the idle reading** — a print that sat at idle-0 loaded fine
   and produced a real part, so that test only yields false negatives.
2. **Check the gcode draws from the slot you think it does.**
   `grep -a "^; filament used \[g\]"` shows usage per slot *in position order*,
   and `grep -a "M6211 A1 L[0-9]* T[0-9]*"` shows which tool it loads.
   **Black is the FIRST slot (`T0`); red is the SECOND (`T1`).** Every job drawn
   from `T0` has succeeded here; `T1` has failed to auto-load twice.
3. **Confirm the uploaded file is really gcode.** `list_files` shows a real job
   with populated `layer` / `print_time` / `color_map`. A `.3mf` uploads happily
   and sits inert at `layer: 0` — see gotcha #35.
4. **`Ack: 0` from `start_print` is not proof.** Confirm `state: 2` with a
   non-empty `TaskId`.

### Judging the result

`task_status: 1` only means the gcode ran to the end. **The chamber camera
cannot see the plate centre** — it looks across the front lip, so a snapshot
reads empty both before and after a good print. A human has to look. Ask them
about the **purge line** specifically: no purge line means filament never
reached the nozzle; a purge line with no part means adhesion.

Watch the flag *during* the run too, not just at the start — poll rather than
sleeping until the end, because a warm bed collapses the ~12 minute preamble to
about 3 and it is easy to sleep straight past the window where aborting would
still have saved the filament.

## Reference 3MF template (one-time setup)

`nfc-build-3mf` reads printer/process settings from `tmp/latest/slicer_template/`. To populate that:

1. In Elegoo Slicer, set up a project the way you want it for these beads (Centauri Carbon 2, PLA filament slots in the right positions, layer height 0.12 mm, 100% infill, no supports).
2. **Save Project As** → `tmp/latest/template.3mf`.
3. Extract it: `cd tmp/latest && unzip template.3mf -d slicer_template/` (the bash way) or right-click in Explorer → 7-zip → extract to `r1_extracted\`.
4. From now on, every `nfc-build-3mf` run produces a 3MF that opens with that same printer/process profile.

You only do this once (or whenever you change printer/filament setup).

## The slow path — manual import (when you don't have a 3MF template)

If you don't have a reference 3MF set up yet, drop the three STLs in directly:

1. Drag `tmp/latest/Bottom.stl`, `Top.stl`, `Decoration.stl` onto the build plate.
2. Select `Top` and `Decoration` in the object list (Ctrl-click) → right-click → **Combine into one object** (or "Merge as parts").
3. Click each part and assign filaments:
   - `Bottom` → Filament 2 (red)
   - `Top` part → Filament 2 (red)
   - `Decoration` part → Filament 1 (black)
4. **Process** panel:
   - Layer height: **0.12 mm** (decoration is 0.5 mm tall = ~4 layers)
   - Infill: **100%**
   - Supports: **off**
   - Wipe / prime tower: **on** (default size is fine)
   - Brim: **off** (no brim — the parts have plenty of bed adhesion at this footprint)
5. Slice and verify the layer preview at Z ≈ 2.5 mm shows the spiral splitting from red to black.

## Print

Send the gcode to the printer. Total print time at 0.12 mm / 100% infill / 20 mm bead: **~20–30 minutes per half** including the wipe tower. The Centauri Carbon 2 auto-feeds the right filament at every transition — zero operator intervention.

## After printing

1. Drop the **NTAG215 sticker** (10 mm dia) into the bottom half's NFC pocket recess. It sits flush.
2. Press the top half down onto the bottom — the 3 pegs friction-fit into the matching peg holes. No glue.
3. String through the 2 mm hole in the head of the bead.

If the press-fit feels loose, increase `PEG_CLEARANCE` in `beads/<charm>/build_<charm>.py` (currently 0.1 mm); rebuild + reprint. Too tight: decrease.

## Verifying before you print

`nfc-verify-stls` is the pre-print guard:

```sh
uv run nfc-verify-stls
```

It loads the 3 STLs in `tmp/latest/` via `trimesh` and checks:

| Check | What |
|---|---|
| `geometry` | vertex/face counts > 0 |
| `watertight` | manifold (every edge has exactly 2 face uses) |
| `bed-flat` | `Bottom` and `Top` start at z=0 |
| `diameter` | within ±1.5 mm of the expected 20 mm |
| `thickness` | bottom 4 mm ±0.5, top 2.5 mm ±0.3, decoration relief 0.5 mm ±0.2 |
| `decoration on top` | gap top_max → deco_min in [-0.02, +0.10] mm |
| `decoration X/Y aligned` | top center and decoration center within 1 mm X / 2 mm Y |

Exits non-zero on any failure → safe to wire into a pre-print git hook.

## File reference

| Path | What |
|---|---|
| `tmp/latest/bead_multicolor.3mf` | **The one to drag into Elegoo Slicer** |
| `tmp/latest/Bottom.stl` `Top.stl` `Decoration.stl` | Individual STLs (manual flow) |
| `tmp/latest/manifest.txt` | Audit trail of the latest export |
| `tools/build_3mf.py` | The 3MF builder (`nfc-build-3mf`) |
| `tools/verify_stls.py` | The verifier (`nfc-verify-stls`) |
| `.claude/skills/bead-stl-export/export.py` | The Blender-side STL exporter |
| `prompts/nfc-bead/prompt.md` | Technical bead recipe (canonical) |

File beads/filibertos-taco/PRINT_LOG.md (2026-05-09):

# Filiberto's Taco — Print Log

Append-only, newest at the top. Every physical print of this charm gets one entry: what was printed, what failed, what changed for next time.

---

## v6-blocks-2color — 2026-05-08 — not yet printed (body=shell)

Simplification of v5: drop the DecorationShell entirely. The bead body
(Bottom + Top) is printed directly in shell yellow — it IS the shell.
Only the filling needs its own decoration STL on top.

**Filaments: 2** (was 3 in v5).
- Body: yellow shell color
- DecorationFilling: green lettuce/filling

Same geometry, simpler print bundle.

`bundle_3mf.py` (new): emits a multi-decoration 3MF where each
`Decoration*.stl` becomes its own component in the Top assembly. The
stock `nfc-make-3mf` only knew one Decoration slot, which collapsed
the multi-color separation. Use `bundle_3mf.py` for any charm with >1
decoration STL.

## v5-blocks — 2026-05-08 — not yet printed (Filibertos block-color, 3-filament)

Third stylistic variant: 3-color flat blocks like the actual Filibertos
logo. Yellow shell forms the base; green filling sits on top with the
open mouth pointing right (matches the source's 3/4 perspective);
red body shows as a thin rim around the silhouette.

Key extraction change: **shell = silhouette MINUS filling** (rather than
shell = yellow color cluster). The source image's yellow shell is mostly
hidden behind green lettuce; the visible-yellow color cluster only
captures where shell PEEKS through, giving a thin sliver. By making shell
= "everything in the silhouette that isn't filling", the shell takes on
its full logo-correct proportion.

Two engineering bugs caught and fixed during this iteration:

1. **Decoration cropper inherited peg-socket holes from Top**.  My pipeline
   was duplicating Top to make the decoration cropper. Top has peg
   sockets cut INTO it. After moving the cropper's verts up, the socket
   holes became open tubes through the cropper. INTERSECT with decoration
   punched matching holes through the show face → 3 visible bare-show-face
   circles at the peg XYs.

   Fix: `_build_silhouette_cropper()` re-imports `silhouette.svg` directly
   and extrudes a clean tall slab with no peg/NFC features. Use this as
   the decoration cropper instead of duplicating Top.

   This is a generic gotcha that applies to ANY multi-color charm — should
   be backported to the recipe and `build_charm.py.example`.

2. **Multi-SVG decorations fail when joined raw**. `BLOCK_GROUPS` originally
   tried to load 2 SVGs per region (e.g. `lettuce_dark.svg` + `lettuce_light.svg`)
   and `bpy.ops.object.join` them. The overlapping coplanar 2D regions
   produced 359 non-manifold edges after extrude. Fix: combine the masks
   at extraction-time into a single `region_filling.svg` / `region_shell.svg`
   (morph-close + fill-holes + AND with silhouette). One clean SVG per
   region downstream.

Output: `print/blocks/filibertos-taco-blocks.3mf` (3 filaments —
shell yellow, filling green, body red). All zero non-manifold edges
in Blender; printability PASS.

## v4c-neon — 2026-05-08 — not yet printed (cleanest taco read)

User feedback on v4b: "not 'obviously taco' enough, drop the bottom shell line".

Two design changes:
1. **Removed `DecorationShell`** — a ring around the lower half made the
   silhouette look double-lined and busy.
2. **Replaced `DecorationLettuce` (closed contour) with `DecorationFillingLine`**
   — a single curve tracing only the BOTTOM EDGE of the lettuce blob (where
   filling meets shell). Now the bead silhouette + this dividing line reads
   as a textbook taco: cradle-shaped bun split by a horizontal filling line.

Two manifold issues got fixed along the way:
- **Mask-blur smoothing made things worse** (50+ non-manifold edges per
  decoration). Cause: smoothing each contour independently diverged the
  outer/inner ring offsets so they cross. Reverted to no smoothing on
  ring-stroke contours.
- **EXACT solver leaves coplanar fragments** at ring boundaries after
  INTERSECT with the silhouette cropper. Added `repair_manifold()` to the
  build pipeline: dissolve degenerate edges, delete loose, fill_holes(8),
  remove doubles, reconcile normals. Now every decoration STL is
  watertight (verified via trimesh: `is_watertight=True`, euler=0 for
  ring shapes, euler=2 for solid).

Filaments now reduced to 2: black body + light blue strokes.

`build_filibertos_taco.py` `repair_manifold()` will help every future
ring-stroke decoration in this charm — and is general enough to backport
to the recipe if other charms hit the same EXACT-solver issue.

## v4b-neon — 2026-05-08 — not yet printed (continuous-stroke neon)

Refined v4-neon. Original strokes used boundary-between-mask which produced
fragmented blobs (one ring per leaf). Replaced with merged-blob outlines:
the lettuce mask is morphologically closed (dilate 14 / erode 14 / fill /
keep largest component) before ring-stroking, so all the leaf shapes merge
into ONE blob whose outer contour traces the lettuce as a single line.
Same for the shell.

Result: 3 continuous neon-line strokes instead of ~30 fragments.

| Stroke | Suggested filament | Notes |
|---|---|---|
| `DecorationSilhouette` | light blue | Outer perimeter of the bead |
| `DecorationLettuce` | light blue | Single curve tracing the filling/lettuce blob |
| `DecorationShell` | red or navy | Single curve tracing the shell (taco hard-shell underside) |

Ring stroke width = 0.42 mm (`STROKE_WIDTH_PX = 6` × `0.0708 mm/px`).
Tune via `STROKE_WIDTH_PX` in `extract_strokes.py` (4 for thin, 8 for bold).

## v4-neon — 2026-05-08 — not yet printed (synthwave / stencil look)

A second stylistic variant for the same bead body. Identical Bottom + Top
geometry, but the show-face decoration is **stroke-based** instead of
filled-region:

| Decoration | Source | Suggested filament |
|---|---|---|
| `DecorationSilhouette.stl` | outer perimeter ring of the bead | light blue |
| `DecorationLettuceLine.stl` | boundary stroke between filling and shell | light blue (same as silhouette) |
| `DecorationLettuceVeins.stl` | interior boundaries inside lettuce | red or navy |

Body filament: black (matches the negative-space areas around strokes — looks
like a neon sign on a dark plate).

Build pipeline supports both via `STYLE` (env var `FILIBERTOS_TACO_STYLE`
or scene custom prop `nfc_taco_style`):

```
bpy.context.scene["nfc_taco_style"] = "neon"
exec(open("build_filibertos_taco.py").read(), {"__name__":"__main__"})
```

The STYLE flag toggles which directory of SVGs (`region_*.svg` or
`stroke_*.svg`) gets discovered into `SVG_REGIONS`. Adding more strokes:
just drop another `stroke_*.svg` next to the others and re-run.

Stroke generation lives in `extract_strokes.py` — uses morphological
dilate-XOR on the color masks to derive ring/boundary geometry, then
Fourier-smooths the contours.

Output: `print/neon/filibertos-taco-neon.3mf` (205 KB) plus per-stroke
STLs for filament assignment in the slicer.

## v3 — 2026-05-08 — not yet printed (4-color decoration)

Re-extracted color regions from the JPG using k-means (k=7) instead of hand-coded thresholds. Now produces 4 distinct decoration layers (was 3 in v1):

| Region | px | Notes |
|---|---|---|
| `outline` (#921209) | 45,594 | Red — biggest region; covers most of the silhouette |
| `shell_dark` (#d68a00) | 18,199 | Yellow — small visible band along the lower curve |
| `lettuce_light` (#5fa520) | 10,711 | Bright green highlights |
| `lettuce_dark` (#374806) | 9,583 | Deep green shadows inside the lettuce |
| `shell_light` | (empty) | Pale-yellow cluster collapsed into shell_dark; no separate region |

Build script now auto-discovers `region_*.svg` files via `_discover_regions()` and emits one `Decoration<Camel>` object per region. Adding more regions is now zero-code: drop a new `region_<name>.svg` and re-run.

Visual result captured in `stages/02_v3_4color.blend`. Bare-show-face patches at the peg-socket XYs persist (peg sockets sit in regions that no color cluster covered) — cosmetic only, no geometric change. Same 4 printability checks PASS as v1.

**Open**: shell yellow ended up only as a thin sliver along the bottom edge — most of the lower-curve area got claimed by red outline. Next iteration should re-tune cluster mapping so shell wins where it competes with outline in the lower band.

## v1 — 2026-05-08 — not yet printed

First export. Build completed cleanly:

- 0 non-manifold edges on Bottom and Top.
- 3 pegs validated with center + 8-perimeter raycast (recipe gotcha #21) — all in solid silhouette, ≥1.5 mm NFC clearance.
- String hole tube entirely inside Top half via `HOLE_Z_OFFSET=1.25` (recipe gotcha #23) — bridged twice by slicer, no inner-face notch.
- All 3 decorations cropped to silhouette via INTERSECT with extruded Top duplicate.
- `nfc-printability-check` PASS on cantilever ratios + bed contact + peg edges.
- `nfc-make-3mf` produced `print/filibertos-taco.3mf` from concatenated `Decoration.stl`.

Caught one issue during export iteration: `bead-stl-export` default applied a 180° X-flip to Bottom, but my centered-mesh pipeline produces Bottom already in print orientation. Recipe gotcha #16 — overridden via `bpy.context.scene["nfc_export_flip_override"]` set inside `build_filibertos_taco.py`.

**Open questions for first print:**
- Slicer filament assignments: Bottom in brown PETG? Top in yellow + 3 decoration filaments? Need to set up in slicer before slicing.
- Does the 0.4 mm raised relief read clearly at 25 mm scale, or does it look stamped?
- First-layer adhesion on the Top half — 246 mm² bed contact, plenty of margin.

**Pre-print checklist:**
- Open `print/filibertos-taco.3mf` in Elegoo Slicer.
- Assign 3 filaments to the Decoration components (yellow shell, green lettuce, red outline).
- Layer height 0.16 mm, 100% infill (parts are tiny), no supports.

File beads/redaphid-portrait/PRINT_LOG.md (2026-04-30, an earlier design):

# redaphid-portrait — print iteration log

Append-only record of each print attempt and what was learned. New entries go at the **top**. Each entry: date, version, what was actually printed (parameters), the failure mode (if any), and the parameter changes for the next attempt.

This sits next to `README.md` (which captures *why this charm exists*); the log captures *what we learned by feeding plastic into the printer*. Future charm builds can grep across PRINT_LOGs to predict their own failure modes.

---

## v6 — 2026-04-29 — printable AND assembles with proper snap-fit

Geometry: as v5c except `PEG_CLEARANCE=0.1 → 0.05` mm. Halves radial gap is now 0.05 mm per side (0.1 mm diametric) instead of 0.1 mm per side (0.2 mm diametric). Only Top STL changes — sockets are in Top; Bottom (with pegs) is unchanged.

**Printed**: yes — and the halves snap together with friction grip for the first time across all six print iterations on this charm. Prior versions all assembled but the halves slid apart easily, which we'd been calling "printable" without checking the snap-fit.

**Lesson captured**: the recipe default `PEG_CLEARANCE=0.1` is conservative for a Centauri Carbon 2. On a well-calibrated FDM printer, that's enough slop for the peg to slide in with no friction at all. **0.05 mm radial / 0.1 mm diametric is a better default** for the CC2 specifically; the recipe-level value is worth revisiting once another charm prints on a different printer to confirm.

Open follow-ups (not blocking):
- v6b: chin peg diameter bumped 1.4 → 1.7 mm (the math limit at this position) for additional grip on the centerline. STLs and `top-v6b.3mf` queued in `print/` but not yet printed. Skip unless v6 grip is insufficient over time.

---

## v5c — 2026-04-29 — printable (after slicer Z-seam fix)

Geometry: TARGET_WIDTH=20, THICKNESS=5, **hole moved entirely into Top** via `HOLE_Z_OFFSET=+1.25` (string-hole tube z=[+0.50, +2.00] inside Top's [0, +2.5] half — solid material above and below, no half-circle groove on either inner face). Three pegs: side ear pegs at (±7, 0) at PEG_DIAMETER=**2.6** mm, single centered chin peg at (0, -7.3) at PEG_DIAMETER=**1.4** mm via per-peg diameter override.

**Printed**: yes — but only after switching Z-seam to Random.

**First attempt (Z-seam = Aligned, slicer default)**: right-ear region of the printed Top half accumulated dragged/oozed plastic into a visible stringy mass localized to that one socket. Left ear printed clean, despite essentially symmetric geometry. Photo evidence ruled out the wall-thickness theory (left wall 0.95 mm and right wall 0.65 mm both within recipe tolerance). Diagnosed as the slicer placing the Z-seam on the right edge each layer, compounding tiny seam artifacts over ~20 layers × 3+ color swaps per layer into one visible blob.

**Fix that worked**: Quality → Layers → Z-seam position = **Random**. The seam artifacts are now spread evenly around the perimeter; no single XY accumulates damage. Same multi-filament setup, same prime-tower position — only Z-seam changed.

**Lessons captured**:
- Small multi-color charms (≤25 mm) are highly sensitive to Z-seam placement. **Default Z-seam to Random for any multi-filament bead.** Documented in `print/FILAMENTS.md`.
- The original `verify_pegs` checked only the peg center via raycast; this missed cases where the peg's *perimeter* poked outside the silhouette. Replaced with an 8-point socket-radius perimeter check in v5b. Still an open improvement: add an explicit wall-thickness margin (≥0.5 mm clear between socket edge and silhouette boundary) so geometry that "barely fits" doesn't make it through.
- Centerline chin pegs at PEG_DIAMETER ≥ 1.84 are mathematically infeasible on this silhouette — NFC bottom (y=-6) and silhouette y_min near x=0 (-8.44) inequalities have no overlap once the peg radius is added. Thinner peg only on that one position, via per-peg diameter override, was the correct fix. Adding `(x, y, dia)` 3-tuples to PEG_CANDIDATES is now part of the build script.

---

## v5b — 2026-04-28 — printable but jaw pegs poked through silhouette

Geometry: as v5c except **4 pegs** in a quadrilateral at (±7, 0) + (±4.3, -7.1), all at uniform PEG_DIAMETER=**2.6** mm.

**Printed**: yes, but the two jaw pegs at (±4.3, -7.1) had their sockets visibly carved through the silhouette boundary on the printed Top half. The 8-point perimeter check passed at build time — but the wall thickness from socket edge to silhouette was paper-thin in places, and FDM layer-by-layer printing exposed the failure.

**Fix in v5c**: dropped the jaw pair, restored a single centered chin peg at (0, -7.3) at smaller PEG_DIAMETER=1.4 (centerline at 2.6 mm is mathematically infeasible — see v5c lesson). Added per-peg diameter override to PEG_CANDIDATES.

**Lesson captured**: an 8-point perimeter raycast against the silhouette is necessary but not sufficient. A peg can pass the check while still leaving a wall thinner than one perimeter width, which prints as voids or stringing around the socket. Future verifier upgrade: enforce a wall-thickness margin (e.g., socket edge to silhouette boundary ≥ 0.5 mm at all 8 perimeter points), not just "socket inside silhouette."

---

## v3 — 2026-04-28 — printable

Geometry: TARGET_WIDTH=20, THICKNESS=5, PEG_HEIGHT=1.5, HOLE_DIA=1.5, HOLE_Y=5.5, NFC_POS=(0,-1), pegs at (±8,0) + (0,-8). Wall above hole = 2.21 mm.

**Printed**: yes. Pegs grip; string hole holds the cord without snapping.

**Lesson captured**: sub-1 mm wall above the string hole snaps under cord load. The printability-check skill now warns; the recipe gotcha #13 documents the placement rule.

---

## v2 — 2026-04-27 — couldn't print

An attempt at a symmetric front/back portrait (raised decoration on both faces) created cantilever geometry the slicer rejected. Approach abandoned; the path-not-taken was removed from the build script in v3.

**Fix in v3**: drop the symmetric-back attempt. Bottom prints in canonical orientation (silhouette face DOWN to plate, pegs UP) — no cantilever, no supports needed.

---

## v1 — 2026-04-26 — printed but pegs too short to grip

Geometry: TARGET_WIDTH=25, THICKNESS=4 (halves 2.0 each), PEG_HEIGHT=1.0, HOLE_DIA=2.0, HOLE_Y=8.5.

**Failure**: Halves snapped together but the friction fit was loose — pegs at 1.0 mm height didn't grip enough to keep the bead closed. Also wall above the hole was only 1.07 mm and bent under cord tension.

**Fix in v2**: PEG_HEIGHT 1.0 → 1.5 mm (recipe default). THICKNESS 4 → 5 mm so the thinner halves still have ≥ 0.7 mm wall above the sockets. HOLE_Y 8.5 → 6.6 mm to thicken the wall above the hole.

**Lesson**: Don't drop PEG_HEIGHT below the recipe default 1.5 mm to "save space" — 1.0 mm pegs don't grip. If thickness is constrained, thicken the bead instead.

---

## How to read this log

- **Top entry = current state**. Cross-reference with `redaphid-portrait.blend` (latest geometry) and `print/redaphid-portrait.3mf` (latest slicer-ready bundle).
- Each entry's "lesson captured" is the one-liner that should propagate to the recipe / GUIDE / printability-check skill if it generalizes beyond this charm.
- Bug fixes that don't change print parameters (build script refactors, skill updates, etc.) belong in commit messages, not here.

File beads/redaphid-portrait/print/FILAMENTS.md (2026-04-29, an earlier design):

# redaphid-portrait — filament + slicer config

The per-charm print recipe. Lives next to the STLs / 3MFs so anyone re-slicing this bead has the color map and the must-flip slicer settings in one place. Generic printer config (multi-color workflow, layer height defaults, etc.) lives in `../../../print/PRINT_GUIDE.md`.

## Filament slot → color → part

The four filament slots configured for this charm in Elegoo Slicer (Centauri Carbon 2, all PLA @ 210 °C):

| Slot | Hex | Color | Used for |
|---|---|---|---|
| 1 | `#000000` | Black | **Hair** (object default; Hair has no per-part extruder override → inherits slot 1) |
| 2 | `#FF0000` | Red | _unused on this charm_ — kept loaded for cross-charm consistency |
| 3 | `#FFFFFF` | White | **Decoration** (eyes) |
| 4 | `#0000FF` | Blue  | **Top body** (the face) |

Bottom half is single-color — no slot assignments needed; print whichever color you want for the back/snap face. Most sensible default: blue (slot 4) so it matches the visible edge of the face when the halves are pressed together.

The assignments are baked into the model parts in `top.3mf`'s `Metadata/model_settings.config` as `<metadata key="extruder" value="N"/>` overrides per part. If `top.3mf` is regenerated from STLs via `nfc-make-3mf`, these assignments are LOST and have to be reapplied (Elegoo Slicer → right-click each part → "Edit Process Settings → Filament").

## Slicer settings — verified state

These are the keys that actually control where swap purge goes, with the values from the user's saved Elegoo Slicer project (Multimaterial tab). Ship with these values:

| Setting | Value | Notes |
|---|---|---|
| `enable_prime_tower`  | **1** (on) | 35 mm wide tower with 3 mm brim, parked at (165, 228.5). |
| `flush_into_infill` | **0** (off) | Flush is *not* painted into the bead body. Earlier diagnosis claimed this was the cause of print failures — it was wrong. |
| `flush_into_objects`  | **0** (off) | |
| `flush_into_support`  | **1** (on)  | This charm has no supports → no-op, harmless. |
| `purge_in_prime_tower`| **0** | Likely a deprecated key in this slicer version; the actual purge routing is the `flush_into_*` set above, all of which correctly send purge to the prime tower. Don't change it; it isn't the problem. |
| Z-hop on travel | **≥ 0.4 mm** (recommended) | Defense in depth so a peeled corner can't be caught by a travel move. Verify in Quality → Travel. |
| **Z-seam position** | **Random** (REQUIRED) | Default "Aligned" puts the per-layer seam at the same XY each layer. On a small multi-color charm (≤25 mm) with frequent color-swap travels, those seams compound into a localized blob of stringy plastic — see PRINT_LOG.md v5c first attempt. Random spreads the seams around the perimeter so no single spot accumulates damage. Quality → Layers → Z-seam position. |
| Filament 4 (blue) initial temp | optional **+5 °C** | Worth trying if peeling persists; first deposit after a swap is on a cooled substrate from a nozzle that dipped during cut/load/purge. |

## Flush volumes (mm³ purged on color swap)

Inherited from Elegoo defaults; documented here for reference, not to be edited unless a print still fails after the above settings are correct.

```
                 to: Black  Red   White  Blue
swap from Black:     —     515   667    414
swap from Red:       197   —     693    344
swap from White:     187   369   —      379
swap from Blue:      187   500   768    —
```

The black→blue (414 mm³) and white→blue (379 mm³) swaps are the two that matter for this charm's print order. Both are large; both go through the prime tower if the settings above are correct.

## Print order (one plate per half)

The build pipeline produces two separate 3MFs in this directory:

- **`top.3mf`** — Top body + Hair + Decoration as one merged object with parts. Print face-up; show face is on the top of the print (z = 2.30 mm body, hair at 2.30–2.70 mm, eyes at 2.31–2.81 mm).
- **`bottom.3mf`** — Bottom only. Print silhouette face down (Bottom is exported pre-flipped in print orientation; pegs point up on the print).

Each is sliced and printed independently. The two halves are press-fit assembled after both prints complete; no glue needed if the pegs grip.

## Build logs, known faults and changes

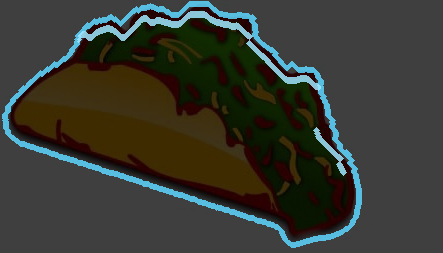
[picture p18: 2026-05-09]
beads/filibertos-taco/stroke_debug.png

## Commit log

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2026-04-26 Backport bead skills + rezz sample scene from theater-mode worktree
    The theater-mode worktree iterated on a structured set of bead-related
    skills — split debug overlays from the cinematic architect look, added
    a defensive STL exporter, and pinned a sample scene so the skills
    always have something to act on. Bringing them back to main.
    - bead-debug-overlays replaces bead-debug-colors with canonical
    Bottom/Top/Decoration object naming
    - bead-architect-mode + theater-mode pair the operational scripts
    (parchment+ink look, 6 seamless-loop camera animations) with the
    protocol/quality-bar layer
    - bead-stl-export strips MA_*/DBG_* and applies a deterministic
    per-part print-orient flip so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
    [rezz_sample.blend]
2026-04-26 Drop legacy bead-name fallback machinery + theater-mode visual updates
    The user's stance: this codebase is for beads going forward; no support
    for legacy <charm>_bottom-style names. In-scene meshes must be exactly
    Bottom / Top / Decoration. Skills resolve them by exact name and fail
    loudly if they're missing.
    Removed throughout:
    - bead-stl-export FALLBACK_SUFFIXES table + suffix-walking resolver
    - bead-architect-mode _find_canonical(*legacy_suffixes) helper
    - bead-architect-mode/architect_off.py suffix-based mesh detection
    - bead-debug-overlays/recolor.py _find_mesh fallback args
    - DBG_NFC alias for DBG_NFCPocket (legacy name)
    - "Top has _top_body suffix, not _top" gotcha (no longer applies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
    [rezz_sample.blend]
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2026-04-26 20mm kandi-bracelet sizing + 3MF-first PRINT_GUIDE rewrite
    verify_stls: EXPECTED_DIA_MM 25.0 → 20.0. Rationale baked into the
    comment: 20 mm is the practical minimum for a Kandi bracelet bead that
    can comfortably host the NTAG215 (10.5 mm dia), 3 friction-fit pegs,
    and a 2 mm string hole. Decoration tolerance widened (±1.5 instead of
    ±1.0) to accept inset spirals.
    samples/rezz_sample.blend: re-saved with the new 20 mm geometry plus
    the architect rig + lights + materials. Drop into Blender via
    tools/launch.ps1 to start a fresh aesthetic session without rebuilding
    the rig.
    print/PRINT_GUIDE.md: rewritten around the 3MF-first workflow.
    Previous guide walked the user through manual STL dra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
    [rezz_sample.blend]
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2026-04-26 Stored animations + nfc-anim-switch — instant scene switch
    Each anim_*.py now writes its keyframes into NAMED Action data blocks
    (BeadAnim_<name>_<role>) with use_fake_user=True so they persist with
    the .blend. Roles: pivot / cam / tgt / sun depending on what each anim
    drives.
    Switching between stored anims is now an O(1) action reassignment —
    no re-keying, no rebuild. anim_switch.py looks up the matching Actions
    for ANIM_NAME, assigns them to the rig (clears the unused roles),
    recomputes scene frame range from the union of active actions' ranges,
    and starts/stops playback (static anims pause at frame 1; animated
    anims play).
    CLI shortcut for the host shell:
    uv run nfc-anim-switch _L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
    [rezz_sample.blend]
2026-04-26 Shrink canonical bead to 17mm Kandi floor
    verify_stls.py: EXPECTED_DIA_MM 20.0 → 17.0. Iterative shrink driven by
    the rezz branch hitting the Kandi floor — smallest diameter that still
    encloses the NTAG215 sticker (10.5 mm), 3 friction-fit pegs, and a
    2 mm string hole with adequate clearance. Comment block updated with
    the new clearance math.
    samples/rezz_sample.blend re-saved with the 17mm halves + dense 6-turn
    0.5mm-arm spiral. All BeadAnim_* actions preserved.
    Backported from theater-mode commits 6bc3894 + 3266439. Skipped the
    iter 09 journal renders (bead-specific).
    [rezz_sample.blend]
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2026-04-27 redaphid-portrait: hair as haircut shape, not face-cutout ring
    Previous iteration had Hair = silhouette - face_contour, which made
    the face oval too big and ate the chin/neck into "hair". Switched to
    the inverse model: extract the HAIRCUT shape directly and let Top's
    full silhouette show face be the skin/face base.
    * extract_silhouette.py: extract_hair_mask uses eye positions as
    anchors. Hair = (silhouette ∩ above eyebrow line) ∪ (silhouette ∩
    far-from-center column AND above jawline). The chin/neck protrusion
    below the jawline stays out → it's automatically face/skin.
    Emits hair.svg (was face.svg, now removed).
    * build_redaphid.py: build_hair_decoration imports hair.svg di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
    [01_built.blend, Bottom.stl, Hair.stl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]
2026-04-27 redaphid-portrait: tighten hair side reach, keep ear tips as hair
    Hair was creeping inward over the eyes. Bumped HAIR_SIDE_FACTOR
    0.65 → 1.2 so the side flaps start a wider margin from the
    silhouette's central column, leaving the cheeks + central face
    zone clearly skin-colored. HAIR_JAWLINE_FACTOR 1.0 → 1.4 so the
    floppy ear tips below the chin stay classified as hair (don't
    get stranded as skin-colored "tabs"). HAIR_EYEBROW_FACTOR 0.5
    → 0.55 to lift the hairline a touch.
    [01_built.blend, Bottom.stl, Hair.stl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]
2026-04-27 redaphid-portrait: fix string hole, cantilever, top-wall thickness
    Three printability bugs caught downstream of the merge:
    1. String hole drilled at z=THICKNESS/2 (the TOP face of the
    centered mesh) instead of the actual z-midpoint → hole was
    entirely inside Top half, no opening on Bottom, you couldn't
    thread a cord through. Now compute z_mid from live verts.
    2. Top assembly cantilevered in slicer because pegs hung below
    Top body. Reverted PEGS_ON_BOTTOM=True so Bottom gets the
    pegs (sticking up) and Top gets sockets (recessed up into
    body) — neither half has overhanging features.
    3. HOLE_Y 8.5 → 7.5 to leave ≥ 2 mm of silhouette wall above
    the hole instead of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
    [01_built.blend, Bottom.stl, Decoration.stl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]
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2026-04-27 redaphid-portrait: print v2 — smaller, longer pegs, symmetric back
    User printed v1 and reported pegs too short to grip + bead could
    shrink. Plus: portrait should be visible on both faces.
    v2 dimensions:
    TARGET_WIDTH 25 → 22 mm (~12% smaller, closer to 17mm Kandi floor)
    THICKNESS 4 → 5 mm (recipe default — needed for full-height pegs)
    PEG_HEIGHT 1.0 → 1.5 mm (recipe default — proper grip)
    Peg layout retuned for the smaller bead — at 22 mm there's no clean
    clearance for a central forehead peg between the (lowered) string
    hole and the NFC pocket. Replaced with two side pegs at the head's
    widest band (y≈0) plus a chin peg at y=-8 (silhouette y_min=-9.3,
    peg edge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
    [01_built.blend, Bottom.stl, Decoration.stl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]
2026-04-27 redaphid-portrait: fix DecorationBack mirror across world z=0
    scale.z=-1 mirrors about the OBJECT's origin, not world z=0. Decoration's
    origin is at the active eye's Z (~2.76) after join, so the duplicate
    landed at the same world Z as the source instead of below the bead.
    HairBack worked because Hair's origin happens to be at world (0,0,0)
    after location-apply.
    Bake the duplicate's transform into vertex data first so the origin is
    at world (0,0,0); then scale.z=-1 mirrors across world z=0 as intended.
    Re-exported DecorationBack.stl + saved .blend with the corrected position
    so the back of the bead now shows matching face detail (eyes + hair) to
    the front.
    [DecorationBack.stl, redaphid-portrait.blend]
2026-04-27 redaphid-portrait: flip Bottom group for print orientation
    User reported back-eyes hovering on the wrong side of the bead in
    the slicer. Cause: with PEGS_ON_BOTTOM=True and the canonical "no
    flip" override on Bottom, the back-decoration ended up at negative
    Z in the exported STL — slicer auto-shifted everything up so the
    eyes landed beneath Bottom's silhouette face instead of on top of
    it.
    Fix in build_redaphid.py: after the live scene is built, rotate
    Bottom + HairBack + DecorationBack 180° around X about Bottom's
    bbox center. This puts Bottom's silhouette face UP (z=+1.5 in the
    live scene), pegs DOWN, and back-decoration raised on top of the
    silhouette face. The "no flip" export overri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
    [01_built.blend, Bottom.stl, DecorationBack.stl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]
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2026-04-28 redaphid-portrait: revert to single-side at v2 dimensions
    User test-printed both the single-side (v1 + v2 fixes) and the
    symmetric-back (v2.5+) versions. The Centauri Carbon 2 had trouble
    with both — supports under the cantilevered pegs scarred the
    silhouette face badly enough that the symmetric-back version came
    out worse than the single-side one.
    Decision: drop back-decoration entirely, keep the v2 dimensional
    fixes (TARGET_WIDTH=22, THICKNESS=5, PEG_HEIGHT=1.5) that the user
    actually wants.
    Build script changes:
    * Removed mirror_decoration_for_back helper.
    * Removed the Bottom-group 180° flip (no longer needed without
    back-decoration on Bottom's silhouette face).
    * Removed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
    [01_built.blend, Bottom.stl, DecorationBack.stl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]
2026-04-28 redaphid-portrait: shrink to 20mm (single-side, retuned pegs)
    Print felt too big at 22mm. Shrunk to 20mm — one notch above the
    17mm Kandi-bracelet floor, but the 10mm NFC pocket needs more
    horizontal margin than 17mm allows, so 20mm is the practical floor
    for THIS silhouette + pocket combo.
    Layout retuned for the smaller silhouette (±10 wide × ±8.46 tall):
    * NFC_POS centered (0, 0) — splits the 1.5mm vertical margin
    above/below evenly so the chin peg has room to clear.
    * Pegs pulled in to ±7 mm sides + chin at -7 (was ±8 + chin -8).
    All three verify with 1.0 mm NFC clearance.
    * HOLE_Y 6.6 → 6.5 — tracks the smaller silhouette top at +8.46.
    Wall above hole is 0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
    [01_built.blend, Bottom.stl, Hair.stl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]
2026-04-28 redaphid-portrait: pull chin peg in + lengthen pegs
    User caught the chin socket grazing the bottom of the neck
    silhouette boundary, plus printed pegs not seating fully in
    their sockets.
    PEG_CANDIDATES chin: (0,-7) → (0,-6.6)
    socket cutter (radius 1.1) was reaching into the narrow
    neck/chin tip. Pulled in 0.4 mm — peg edge at y=-7.6,
    silhouette y_min=-8.46, 0.86 mm clearance.
    PEG_HEIGHT 1.5 → 1.7 mm
    Sockets scale to 2.0 mm (cutter = PEG_HEIGHT + 0.3); wall
    above socket is 0.5 mm — recipe minimum, but the longer
    peg gives more contact length and better friction grip.
    Verifier passes all three pegs. Bottom Z extent grew 4.0 →
    4.2 mm (2.5 body + 1.7 pegs)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
    [01_built.blend, Bottom.stl, Hair.stl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]
2026-04-28 redaphid-portrait: smaller hole + 20mm + symmetric-back is now opt-in
    Print v3 fixes:
    HOLE_DIA 2.0 → 1.5 mm — wall above hole was snapping
    HOLE_Y 6.6 → 5.5 mm — moves hole lower into the hair band
    TARGET_WIDTH 22 → 20 mm — sync script to user's iteration
    Walls: 8.46 (silhouette top) − 5.5 − 0.75 (radius) = 2.21 mm of solid
    material above the hole (was 0.86 mm), well over the recipe's
    recommended 2.5 mm minimum once the hole shrinks.
    SYMMETRIC_BACK flag added (default OFF) so the canonical print
    orientation is the default — Bottom prints silhouette face DOWN
    to plate, pegs UP, no cantilever, no supports needed. Flipping
    the flag on adds HairBack + DecorationBac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
    [01_built.blend, 03_user_edits.blend, Bottom.stl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]
2026-04-28 add bead-printability-check skill — pre-flight slicer-failure gate
    A Claude skill + companion CLI that runs trimesh-based checks on the
    latest bead STL set in tmp/latest/. Catches the failure modes we ran
    into the hard way during physical printing of redaphid-portrait —
    the ones verify_stls.py (geometry-only) misses.
    Checks:
    * wall above string hole — soft warn when the cross-section diff
    looks like a real hole notch under the recipe's 2.5 mm minimum
    (heuristic; see SKILL.md "Known limitations")
    * cantilever — area at z=0.5 vs z=2.5; ratio > 5 means the body
    is suspended on thin features (the SYMMETRIC_BACK pegs-down
    failure mode that broke the v2 print)
    * peg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
    [redaphid-portrait-1side.3mf]
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2026-04-28 add bead-build orchestration skill — full pipeline in one trigger
    Chains the six steps that we'd been running by hand every iteration:
    1. rebuild via Blender MCP (exec build_<charm>.py with main()
    namespace so __name__=='__main__' fires; wipes FullBead* +
    canonical objects beforehand)
    2. exec bead-stl-export's export.py inside the same Blender
    3. nfc-verify-stls (geometry hygiene)
    4. nfc-printability-check (slicer-failure gate)
    5. nfc-make-3mf (writes tmp/latest/bead.3mf)
    6. cp artifacts -> beads/<charm>/print/, renaming bead.3mf to
    <charm>.3mf
    Charm auto-detected from current git branch name (matches
    beads/<branch>/), or pass --charm explicitly. Build-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
    [01_built.blend, Bottom.stl, Hair.stl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]
2026-04-28 strip SYMMETRIC_BACK — symmetric-front/back portrait isn't coming back
    The "raised decoration on both faces" experiment from v2 forced a
    Bottom flip, made the pegs cantilever, and never printed. v3 turned
    the flag off and shipped. The toggle is now dead weight — removing
    it everywhere so future-Claude doesn't get tempted to flip it on.
    Files touched:
    beads/redaphid-portrait/build_redaphid.py
    - Drop SYMMETRIC_BACK config flag
    - Drop mirror_decoration_for_back() helper (only caller was the
    flag's True branch)
    - Inline the canonical "Bottom in print orientation already, no
    flip" path; the conditional flip logic + bottom_group machinery
    is gone
    .claude/ski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
    [01_built.blend, Bottom.stl, Hair.stl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]
2026-04-29 redaphid-portrait: v5b — hole-in-Top + 4 thicker pegs at perimeter-verified clearance
    THICKNESS back to 5.0mm (v3 baseline) but with the entire string hole now
    inside Top via HOLE_Z_OFFSET=+1.25 — eliminates the inner-face groove that
    was disrupting first-layer adhesion at the hair band. PEG_DIAMETER bumped
    2.0→2.6 for grip, with 4 pegs at (±7,0) and (±4.3,-7.1) — the centerline
    chin peg was geometrically infeasible with thicker pegs (NFC pushes <-7.8,
    silhouette pushes >-7.04 once peg edges actually have to fit), so the chin
    becomes a symmetric pair off-axis. New FILAMENTS.md captures the per-charm
    slicer config (slot→color→part map + must-flip Multimaterial settings).
    Co-Aut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
    [01_built.blend, Bottom.stl, Hair.stl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]
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2026-04-29 redaphid-portrait: log v5b/v5c print iterations + capture Z-seam=Random as the fix
    PRINT_LOG entries for the two prints since v3, plus the slicer-side fix
    that finally cleared the right-ear stringing:
    - v5b — 4-peg quadrilateral printed but jaw pegs visibly poked through the
    silhouette (8-point perimeter check passed; wall thickness margin did not).
    - v5c — single centered chin peg via per-peg diameter override. First print
    had localized stringy plastic accumulating at the right ear over many
    layers; diagnosed as Z-seam=Aligned compounding seam artifacts on a fixed
    XY each layer. Switching Z-seam to Random fixed it without any geometry
    change. Saved working slicer project as p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
    [working.3mf]
2026-04-30 redaphid-portrait: v6 — PEG_CLEARANCE 0.1→0.05 finally gets a proper snap-fit
    Six iterations in, the halves snap together with friction grip for the first
    time. Recipe default PEG_CLEARANCE=0.1 mm is conservative for the Centauri
    Carbon 2 — on a well-calibrated FDM printer it's enough slop that the peg
    slides in with zero friction. Halving it to 0.05 mm radial / 0.1 mm
    diametric was the missing piece; only Top changes (sockets are in Top,
    pegs in Bottom keep their dimensions).
    Also queued v6b in print/top-v6b.3mf: chin-peg diameter bumped to 1.7 mm
    (the math limit at the centerline given NFC and silhouette constraints) for
    extra grip if v6 friction loosens with use. Untested — keep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
    [01_built.blend, Top.stl, redaphid-portrait.blend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]
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2026-05-09 filibertos-taco: v3 — k-means re-extraction, 4-color decoration
    Replaces v1's hand-thresholded 3-region extraction with a k-means
    clustering (k=7) that yields 4 distinct decoration layers:
    - shell_dark (yellow)
    - lettuce_dark (deep green shadow)
    - lettuce_light (bright green highlight)
    - outline (red)
    build_filibertos_taco.py now auto-discovers `region_*.svg` files and
    emits one Decoration<Camel> object per region — adding a 5th color
    is zero-code. Each gets its own STL for multi-filament slicer slot
    assignment plus a unified Decoration.stl for the 3MF bundle.
    Other changes:
    - extract_regions.py: standalone re-extractor; sklearn k-means + named-
    region predicate m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
    [02_v3_4color.blend, Bottom.stl, Decoration.stl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]
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2026-05-09 filibertos-taco: v4b-neon — continuous-stroke outlines (was fragmented)
    Replaces v4's boundary-between-mask stroke generation with merged-blob
    outlines. The lettuce mask is morphologically closed (dilate 14 /
    erode 14 / fill / keep-largest) before ring-stroking, so multiple leaf
    blobs merge into ONE shape whose outer contour traces the filling as a
    single continuous line. Same for the shell.
    Result: 3 neon-line strokes (silhouette + lettuce + shell) each
    rendering as one clean curve, instead of ~30 fragmented blobs.
    stroke_lettuce_line.svg → stroke_lettuce.svg (renamed)
    stroke_lettuce_veins.svg → stroke_shell.svg (replaced; veins were too noisy)
    print/neon/ refreshed wi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
    [04_v4b_neon_continuous.blend, Bottom.stl, Decoration.stl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]
2026-05-09 filibertos-taco: v4c-neon — cleaner taco read + manifold repair
    Design feedback iteration:
    - Removed DecorationShell (made silhouette look double-lined)
    - Replaced DecorationLettuce closed-contour with DecorationFillingLine,
    a single curve tracing only the BOTTOM EDGE of the lettuce blob.
    Combined with the silhouette outline this reads as taco-cradle +
    horizontal filling split.
    Manifold fixes:
    - Reverted mask-blur smoothing (smoothing outer+inner ring edges
    independently diverged them, producing self-intersecting volumes).
    - Added repair_manifold() to build pipeline: dissolve_degenerate +
    delete_loose + fill_holes(8) + remove_doubles. Recovers a watertight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
    [05_v4c_neon_taco.blend, Bottom.stl, Decoration.stl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]
2026-05-09 filibertos-taco: v5-blocks — 3-color Filibertos block-color variant
    Third style alongside painted + neon. Yellow shell forms the bead's
    base; green filling sits on top with the open mouth pointing right
    (matching the source's 3/4 perspective); red body shows as a thin rim
    around the silhouette outline. 3 filaments.
    Key change: shell = silhouette MINUS filling (was: shell = yellow color
    cluster). The source's visible-yellow shell only captures where shell
    peeks past the green lettuce — a thin sliver. By taking the full
    not-filling region as shell, the shell occupies its correct logo
    proportion (~half the bead by area).
    Two bugs fixed during this iteration:
    1. Decoration cropper inherit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
    [06_v5_blocks.blend, Bottom.stl, Decoration.stl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]
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2026-05-09 filibertos-taco: v6.1 — fix U-shape notch in filling
    The lettuce mask had a thin yellow wedge at bottom-right that close=3
    didn't bridge, leaving a U-shape concavity in the green decoration
    that exposed yellow shell underneath. Bumped close=6 + post-blur
    gaussian (sigma=2) to bridge boundary concavities, not just interior
    holes.
    Filling is now a smooth blob with the open mouth on the right and a
    clean curve along the bottom shell.
    [08_v6_1_smoothed_filling.blend, Bottom.stl, DecorationFilling.stl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]
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2026-05-09 filibertos-taco: v8 — bottom-only trim kills filling tongue
    User: the green has a tongue stretching down the bottom-right that
    overrides where the shell should be. Don't flat-clamp horizontally
    (v7-attempt broke natural contours) — only trim the bottom edge.
    New trim_bottom_px parameter on combine_region(): keep pixel (y,x) True
    only if (y+1..y+N, x) are all True. Anisotropic erosion that pulls the
    bottom contour up by N pixels while leaving top/left/right contours
    alone.
    Filling now: 9px uniform inset (rim around all sides) + 14px bottom-
    only trim (kills the tongue). Top frill bumps preserved; left + right
    shell tips preserved; bottom-right shell rim now clearly visible.
    Co-Authored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
    [10_v8_yclamp_filling.blend, 11_v8_bottom_trim.blend, Bottom.stl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]
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2026-05-09 filibertos-taco: outline ring derived from silhouette polygon (no gaps)
    Replace mask-based outline ring with shapely polygon offset of the
    SAME silhouette polygon used for the bead body. Outer edge of the
    red ring is now exactly aligned with the silhouette outer edge —
    no gaps where they would mismatch due to different smoothing.
    Also: use bmesh.ops.bridge_loops for ring polygons instead of
    triangle_fill — clean quad topology from outer + inner edge loops.
    [filibertos-taco_charm.blend]
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2026-05-09 filibertos-taco: bundle_3mf — semantic top-level object names (no '_5' rewrite)
    Slicers were rewriting component names like `top_with_decorations_5`
    because the parts were nested inside a ComponentsObject and the
    slicer flattens the hierarchy with auto-suffixes.
    Fix: emit each part as a TOP-LEVEL <object> with its semantic name
    (Bottom, Top, DecorationFilling, DecorationLettuceSeparator,
    DecorationInteriorDetail, DecorationShellOutline). Co-locate the
    Top + decoration parts via shared build-item offset so the slicer
    sees them at the same plate position.
    Verified by parsing 3D/3dmodel.model XML: all 6 objects have
    clean semantic names.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
    [filibertos-taco-blocks.3mf]
2026-05-09 filibertos-taco: NFC perimeter check + bumped NFC_POS to (0, 1.5)
    Two related fixes:
    1. NFC perimeter check (mirrors recipe gotcha #21 for pegs but for the
    NFC pocket): 16-point raycast around the pocket boundary; if any miss
    solid silhouette, abort with a message. Catches an entire class of
    bugs where the pocket clips past the silhouette outer boundary
    leaving paper-thin or open walls.
    2. Bumped NFC_POS y from 0.5 to 1.5 — at radius 5.25mm centered at y=0.5
    the pocket sat ~3.75mm from the silhouette's lower edge, which was
    visually close in the slicer's 3D view. y=1.5 gives ~4.75mm clearance.
    Also reverted bundle_3mf.py back to ComponentsObject wrapping (commit
    5e7e6c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
    [20_v15_nfc_y_bumped.blend, Bottom.stl, DecorationFilling.stl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]
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2026-06-14 redaphid-portrait-v2: portrait outline bead on the new design
    Variant of redaphid-portrait that KEEPS the portrait outline as the bead shape
    (not a round medallion), with the new structural design from gymnast-medallion:
    - asymmetric thin halves: thick Bottom 2.0 (NFC + sockets + hole) / thin Top 1.5
    (hair + eyes + peg bases) = 3.5mm body (was 4.0 symmetric)
    - single-half string hole, 1.2mm, fully in the thick Bottom (~0.4mm walls)
    - snap-fit pegs at 0.05mm clearance with 0.3mm chamfered tips that self-start
    (fixed the coplanar cone-tip union so each peg welds to Top as one body)
    Direct headless export of the 4 print-oriented STLs (Top flipped show-face-down,
    pegs up) + 4-color 3MF. All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
    [01_built.blend, Bottom.stl, Decoration.stl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]
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
